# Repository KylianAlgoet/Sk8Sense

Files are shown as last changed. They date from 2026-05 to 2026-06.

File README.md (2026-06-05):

# SK8Sense

Movement Intelligence System voor skateboard coaching.

SK8Sense is een werkend prototype van een slimme skateboardcoach. Het systeem bestaat uit een sensormodule onder het skateboard en een mobiele app die live beweging, druk, impact en trickpogingen zichtbaar maakt. Het board meet wat een skater zelf niet kan zien: pop, airtime, rotatie, landing en drukverdeling.

Het project werd gemaakt door Kylian Algoet als Final Work voor Multimedia & Creative Technology, academiejaar 2025-2026.

## Status

Dit is geen los idee en geen enkel schermconcept. SK8Sense is een werkend hardware- en softwareprototype:

- de ESP32 leest een MPU6050 en vier FSR-druksensoren uit;
- de sensordata wordt via Bluetooth Low Energy naar de app gestuurd;
- de app toont live pitch, roll, impact, FSR-druk en trickstatus;
- sessies kunnen gestart, gevolgd, gestopt en opgeslagen worden;
- trick-detectie gebeurt regelgebaseerd op de firmware;
- AI-coaching geeft korte feedback op basis van sessie- en trickdata;
- de sensormodule zit in een fysieke 3D-geprinte behuizing voor montage onder het deck.

Terminologie: de eerste breadboardfase was een technische haalbaarheidstest. Het eindresultaat van dit project is een werkend prototype.

## Onderzoeksvraag

Hoe kan technologie het leren van skateboardtricks toegankelijker, meetbaar en motiverender maken zonder dat er constant een fysieke coach nodig is?

SK8Sense beantwoordt die vraag door een bestaand skateboard te veranderen in een meetinstrument. Het prototype registreert elke poging, vertaalt ruwe sensordata naar begrijpelijke feedback en helpt de skater gerichter oefenen.

## Het Probleem

Skateboardtricks leren gebeurt vaak op gevoel. Beginners leren via trial-and-error, YouTube, TikTok of videoanalyse achteraf. Dat helpt, maar het blijft moeilijk om te begrijpen wat er precies fout liep tijdens een poging.

Een ollie of kickflip duurt maar een fractie van een seconde. De belangrijkste techniek zit in ongeveer 200 ms: pop, voetdruk, airtime, rotatie, catch en landing. Een coach kan niet elke microbeweging zien. Een skater die zichzelf filmt ziet vaak wel dat het fout ging, maar niet waarom.

SK8Sense lost dat op door het board zelf te laten meten.

## De Oplossing

SK8Sense bestaat uit twee grote delen:

1. Een sensormodule onder het skateboard.
2. Een mobiele app voor live feedback, sessies, learning en coaching.

De sensormodule meet 100 keer per seconde hoe het board beweegt. De app maakt die data bruikbaar: live dashboard, trickfeed, session summary, learning tab en AI-coaching.

Belangrijk: de trick-detectie is bewust niet als black-box AI gebouwd. De ESP32 herkent tricks met transparante, regelgebaseerde logica op basis van fysica. De AI zit in de coachinglaag, niet in de detectielaag.

## Kernzin

Een coach kijkt naar een leerling. Een sensor kijkt naar elke poging.

## Wat Werkt Er Al?

### Hardware

- ESP32-S WROOM leest alle sensoren uit.
- MPU6050 meet versnelling en rotatie.
- Vier FSR 402 druksensoren meten voetdrukzones.
- BLE-advertising en datastream werken.
- Batterijvoeding werkt stabiel met TP4056 en MT3608 boost converter.
- De module zit in een finale PETG-behuizing met aparte deksel.
- Montage onder het deck is uitgewerkt via centrale positie tussen de trucks.

### Firmware

- 100 Hz sensor sampling.
- JSON-payload via BLE Notify.
- Regelgebaseerde trick-detectie.
- Airtime-detectie via acceleratie.
- Flip- en shove-it-detectie via gyroscooppieken.
- FSR-data wordt meegestuurd naar de app.
- I2C-stabiliteit verbeterd met 100 kHz bus clock.

### App

- Login en registratie via Firebase.
- Onboarding flow.
- BLE scan en connect flow.
- Live dashboard met pitch, roll, impact en FSR-bars.
- Live board visualisatie.
- Start/stop live session.
- Trick detection feed.
- Session summary.
- Trick breakdown.
- Session log via Firestore.
- Learning tab voor ollie, kickflip en pop shove-it.
- Trick intro met stappen.
- Practice mode met pogingfeedback.
- Profile en history flow.
- AI Coach feedback via Claude Haiku.

## Product Flow

De app is opgebouwd rond de echte flow van een skater:

1. Open de app.
2. Log in of registreer.
3. Zet het board aan.
4. Scan naar `SK8Sense`.
5. Verbind via BLE.
6. Kalibreer het board plat.
7. Start een live session.
8. Skate en laat het board data meten.
9. Bekijk live feedback en trick-detecties.
10. Stop de sessie.
11. Bekijk summary, trick breakdown en AI-analyse.
12. Oefen verder via de learning tab.

## Live Session

De live session is het hart van SK8Sense.

Tijdens een live session toont de app:

- sessietimer;
- aantal detecties;
- status van de sensorconnectie;
- pitch;
- roll;
- impact;
- tail pressure;
- FSR-druk voor nose, heel, toe en tail;
- live board visualisatie;
- detection banner bij trickherkenning;
- recente trickfeed;
- AI-tip of coachingtip.

De app gebruikt de firmware-output als primaire detectiebron. Wanneer de ESP32 een trick classificeert, logt de app die poging in de actieve sessie.

## Session Summary

Na `END SESSION` toont de app een summary:

- totale duur;
- aantal tricks;
- tricks per minuut;
- max impact;
- trick breakdown per tricktype;
- volledige trick log met timestamps;
- AI Coach analyse van de sessie.

Wanneer een gebruiker ingelogd is, wordt de sessie opgeslagen in Firestore. Daardoor kan de app sessiegeschiedenis en progressie tonen.

## Learning Tab

De learning tab helpt skaters om de MVP-tricks stap voor stap te begrijpen.

| Trick | Doel |
| --- | --- |
| Ollie | De basis: pop, slide, board levelen en landen |
| Kickflip | Flick, fliprotatie, catch en landing |
| Pop shove-it | Tail scoop en horizontale boardrotatie |

Elke trick heeft:

- eigen trick card;
- moeilijkheid;
- categorie;
- korte beschrijving;
- movement breakdown;
- stappen met tips;
- start practice knop.

## Practice Mode

Practice mode is de oefenflow van de app. De skater werkt eerst door losse stappen en daarna door volledige pogingen.

Practice mode bevat:

- timer;
- huidige trick;
- stapvoortgang;
- boardvisualisatie;
- pogingresultaat;
- korte coachingtip;
- rounds van vijf pogingen;
- success rate per round;
- practice summary.

Als een board verbonden is, toont de app dat er live sensorcontext aanwezig is. Zonder board kan practice mode in simulatiemodus gebruikt worden om de learning flow te testen.

## Detectie: Geen Black Box

SK8Sense gebruikt geen AI om de trick zelf te raden. De detectie is regelgebaseerd en draait op de ESP32. Dat maakt de werking uitlegbaar en snel.

De firmware kijkt naar:

- totale acceleratiemagnitude;
- airtime;
- landing impact;
- piekrotatie rond X-as;
- piekrotatie rond Y-as;
- FSR-drukwaarden als extra context.

State machine:

```text
IDLE -> AIRTIME -> LANDING -> IDLE
```

Belangrijkste drempels:

```cpp
AIRTIME_MAG_MAX = 6.5f
LAND_MAG_MIN    = 15.0f
AIRTIME_MIN_MS  = 80
KICK_THRESHOLD  = 180.0f
HEEL_THRESHOLD  = 180.0f
SHUV_THRESHOLD  = 160.0f
```

Ondersteunde detecties:

| Trick | Detectielogica |
| --- | --- |
| Ollie | Airtime zonder dominante flip- of shuv-rotatie |
| Kickflip | Sterke positieve X-rotatie tijdens airtime |
| Heelflip | Sterke negatieve X-rotatie tijdens airtime |
| Backside shuv  | Sterke Y-rotatie in backside richting |
| Frontside shuv | Sterke Y-rotatie in frontside richting |

## AI Coaching

De AI-laag wordt pas gebruikt nadat een trick of sessie al gemeten is. Claude Haiku vertaalt de data naar korte, bruikbare coachingtaal.

De feedbackregels:

- maximaal kort;
- geen lange uitleg;
- skate-taal;
- externe focus;
- gericht op de volgende poging;
- niet "buig je knieen", maar "stay over the bolts".

Voorbeelden van de gewenste toon:

```text
Stay over the bolts.
Pop through the tail.
Catch it closer to the board.
Keep the board under you.
```

## Hardware Architectuur

```text
Skateboard
  ESP32-S WROOM
    MPU6050 via I2C
    FSR nose via ADC
    FSR heel via ADC
    FSR toe via ADC
    FSR tail via ADC
    BLE Notify
      -> React Native app
           live dashboard
           session store
           AI coaching
           Firebase
```

## Hardware Componenten

| Component | Functie | Status |
| --- | --- | --- |
| ESP32-S WROOM 38-pin | Microcontroller + BLE | Werkend |
| MPU6050 | Accelerometer + gyroscoop | Werkend op 100 Hz |
| 4x FSR 402 | Drukzones onder griptape  | Alle 4 geisoleerd werkend |
| LiPo 3.7V 2000 mAh | Batterij | Werkend |
| TP4056 | LiPo laadmodule | Werkend |
| MT3608 | Boost van 3.7V naar 5V | Noodzakelijk en werkend |
| Schuifschakelaar | Aan/uit | Werkend |
| Perfboard | Permanente montage | Gesoldeerd |
| PETG-behuizing | Bescherming onder deck | Finale versie |

## Pinout

| Onderdeel | ESP32 pin | Functie |
| --- | --- | --- |
| MPU6050 SDA | GPIO21 | I2C data |
| MPU6050 SCL | GPIO22 | I2C clock |
| FSR nose pocket | GPIO34 | ADC |
| FSR heel side | GPIO35 | ADC |
| FSR toe side | GPIO32 | ADC |
| FSR tail pocket | GPIO33 | ADC |
| Voeding | VIN/5V | Via MT3608 boost |
| GND | GND | Gemeenschappelijke massa |

FSR voltage divider:

```text
3.3V -> FSR -> ADC pin -> 10k ohm -> GND
```

Belangrijk leerpunt: de 10k pull-down weerstanden moeten naar GND, niet naar SVP/GPIO36.

## Sensorplaatsing

De sensormodule zit centraal onder het deck, tussen de trucks.

Waarom daar:

- de trucks beschermen de module beter tegen directe impact;
- het middelpunt geeft representatieve boardbeweging;
- de module zit niet onder de voeten;
- de montage kan logisch via skateboard bolts en truckposities;
- de sensor verandert het skategevoel niet.

De FSR-sensoren zitten onder het griptape op vier drukzones:

| FSR | Positie | Wat het meet |
| --- | --- | --- |
| Nose pocket | Voorste voet vooraan | Nose press, manual, catch-context |
| Heel side | Hielzijde | Kickflip/flick-context |
| Toe side | Teenzijde | Heelflip/flick-context |
| Tail pocket | Achterste voet | Pop-kracht |

## Behuizing

De behuizing werd iteratief ontwikkeld:

1. Eerste rode PLA-print om maatvoering en indeling te testen.
2. Grotere finale PETG-versie voor de echte integratie.
3. Aparte zwarte deksel.
4. Openingen voor laadpoort, schakelaar en kabeldoorvoer.
5. Montage met skateboard bolts en moeren via de truck-bolt-posities.

PETG is gekozen voor de finale versie omdat het taaier is dan PLA, beter tegen warmte kan en geschikter is voor trillingen onder een skateboard.

## Voeding

De originele aanname was dat een LiPo direct genoeg zou zijn voor de ESP32 NodeMCU. Dat bleek fout.

Probleem:

- LiPo levert 3.7V nominaal en 4.2V volledig geladen.
- De AMS1117-regulator op de ESP32 NodeMCU vraagt ongeveer 4.5V of meer op VIN.
- BLE-pieken deden de spanning zakken.
- Resultaat: BLE advertising werkte niet betrouwbaar op batterij.

Fix:

```text
LiPo -> TP4056 -> MT3608 boost naar 5V -> schakelaar -> ESP32 VIN
```

Na de MT3608 werkte BLE op batterij stabiel.

## BLE Protocol

Device name:

```text
SK8Sense
```

Service UUID:

```text
4fafc201-1fb5-459e-8fcc-c5c9c331914b
```

Characteristic UUID:

```text
beb5483e-36e1-4688-b7f5-ea07361b26a8
```

Voorbeeldpayload:

```json
{
	"ax": -4.3,
	"ay": 0.4,
	"az": 8.0,
	"gx": -5.8,
	"gy": 1.3,
	"gz": 0.6,
	"trick": "none",
	"f1": 0,
	"f2": 0,
	"f3": 0,
	"f4": 0
}
```

Velden:

| Veld | Betekenis |
| --- | --- |
| `ax`, `ay`, `az` | Acceleratie in m/s^2 |
| `gx`, `gy`, `gz` | Gyroscooprotatie in deg/s |
| `trick` | Herkende trick of `none`  |
| `f1` | FSR nose, 0-1023 |
| `f2` | FSR heel, 0-1023 |
| `f3` | FSR toe, 0-1023 |
| `f4` | FSR tail, 0-1023 |

## Testresultaten

Het prototype werd getest via PlatformIO Serial Monitor, Expo dev client en field tests.

### Bench Tests

| Test | Resultaat |
| --- | --- |
| Boot test | Status actief binnen 3 seconden |
| BLE bereik | Stabiel tot ongeveer 8 meter in open ruimte |
| Sample rate | 100 Hz gedurende 60 seconden |
| Packet loss | Minder dan 2 procent |
| Batterijstream | 6+ uur bevestigd met 2000 mAh LiPo |
| FSR isolatie | Alle 4 sensoren onafhankelijk werkend |
| Pitch/roll | Live zichtbaar in app |

### Gemeten waarden

| Situatie | Waarde |
| --- | --- |
| Rust plat | AX ongeveer -4.38, AY ongeveer 0.40, AZ ongeveer 7.96 m/s^2 |
| Gyro drift stil | Minder dan 0.5 deg/s |
| FSR ruis los | Ongeveer 300 ADC, weggefilterd met threshold |
| Live kanteling  | Pitch -21.4 graden, roll 26.7 graden correct zichtbaar |

### Field Test

Het prototype werd niet alleen op tafel getest. Er is ook getest in een echte skatecontext met board, spot en live dashboard. De field test bevestigde dat hardware, app-interface en gebruikssituatie samen logisch voelen.

Getest:

- board statisch bewegen;
- pitch en roll kantelen;
- FSR-drukzones activeren;
- volledige sessieflow;
- kickflip/ollie/shuv detectie via gyro en airtime;
- appfeedback tijdens live sessie.

## Wat Misging En Hoe Het Gefixt Is

De fouten zijn belangrijk omdat ze bewijzen dat het prototype echt gebouwd, getest en verbeterd werd.

| Fail | Oorzaak | Fix |
| --- | --- | --- |
| BLE werkte niet op batterij | AMS1117 kreeg te weinig VIN uit LiPo | MT3608 boost converter toegevoegd |
| FSR cross-talk | Pull-downs naar SVP/GPIO36 in plaats van GND | Alle weerstanden naar GND verplaatst |
| Alle FSR's lazen 0 | Losse 3.3V en koude lassen | Verbindingen opnieuw gesoldeerd |
| MPU6050 viel weg bij trilling | I2C op 400 kHz te gevoelig op perfboard | `Wire.setClock(100000)` |
| Boardnaam niet zichtbaar in BLE scan | Naam zat in scan response | Service UUID expliciet geadverteerd |
| 3D viewer instabiel | expo-gl incompatibel met RN 0.81.5 | Stabiele Animated fallback |
| Pitch/roll bleef 0.0 graden | Stale closure in BLE callback | Waarden direct uit sensorData berekend |

## Markt En Doelgroep

SK8Sense richt zich op een duidelijke marktgap: veel skaters leren zelfstandig, maar er bestaat weinig toegankelijke sport-tech die specifiek skateboardtricks meet en coacht.

Doelgroep:

- leeftijd 14-25;
- beginner tot intermediate;
- skaters die tricks willen leren zonder dure lessen;
- skaters die zichzelf al filmen maar niet weten waarom een poging misgaat;
- coaches die objectieve data per leerling willen.

Personas uit het magazine:

| Persona | Profiel | Waarom SK8Sense helpt |
| --- | --- | --- |
| Kobe, 16  | Beginner, skatet 6 maanden  | Wil weten wat fout gaat bij tricks |
| Lars, 22  | Intermediate, data-gedreven | Wil consistentie meten |
| Elien, 28 | Skatecoach | Wil data over elke poging van leerlingen |

## Scope

### Must Have

- BLE-verbinding ESP32 naar app.
- Realtime IMU-streaming op 100 Hz.
- Trick-detectie voor ollie, kickflip en shove-it logica.
- Sessies opnemen en bewaren.
- Firebase gebruikersauthenticatie.
- Live board visualisatie met pitch en roll.

### Should Have

- Vier FSR-druksensoren.
- AI-coaching via Claude Haiku.
- Profiel met statistieken.
- Sessie-samenvatting.
- Kalibratie van sensoren.

### Could Have

- 3D skateboardvisualisatie.
- Leermodule met stap-voor-stap tricks.
- Video-synchronisatie.
- Multiplayer of vrienden vergelijken.

### Bewust Niet In MVP

- TensorFlow Lite on-device ML.
- Volledig FSR-gebaseerde trick-detectie.
- iOS-build.
- Betaalsysteem.

## Design

Het design-systeem heet MIS v3: Movement Intelligence System.

De app moest niet voelen als een bankapp of generieke fitnessapp. De visuele richting is een neo-brutalist performance OS: donker, hoekig, data-gedreven en geloofwaardig binnen skatecultuur.

Designprincipes:

- data moet snel scanbaar zijn tussen pogingen;
- elke screen heeft een duidelijke taak;
- feedback moet bruikbaar zijn, geen decoratie;
- skatecultuur en technische precisie moeten samenkomen;
- statuskleuren worden functioneel gebruikt;
- oranje accentkleur markeert actie, detectie en feedback.

Belangrijke stijlkeuzes:

| Element | Keuze |
| --- | --- |
| Achtergrond  | Void black |
| Accent | Signal orange |
| Display font | Archivo |
| Data labels  | IBM Plex Mono |
| Body text | Space Grotesk |
| Componenten  | Ticked panels, RegStrip, MotionAI, chips, stat grids |

Design tokens:

```text
app/design-tokens.js
docs/design/design-tokens-reference.js
```

## Tech Stack

### App

| Onderdeel | Technologie |
| --- | --- |
| Framework | React Native |
| Runtime | Expo SDK 54 |
| Navigatie | React Navigation |
| State | Zustand |
| BLE | react-native-ble-plx |
| Auth | Firebase Auth |
| Database  | Firestore |
| AI | Anthropic Claude API |
| Fonts | Archivo, IBM Plex Mono, Space Grotesk |

### Firmware

| Onderdeel | Technologie |
| --- | --- |
| Platform | ESP32 Arduino  |
| Build tool  | PlatformIO |
| BLE stack | NimBLE-Arduino |
| JSON | ArduinoJson |
| IMU library | MPU6050 |
| Sensor bus  | I2C op 100 kHz |

## Projectstructuur

```text
SK8Sense/
  app/
    App.js
    app.json
    package.json
    screens/
      HomeScreen.js
      ConnectScreen.js
      DashboardScreen.js
      SessionSummaryScreen.js
      LearningScreen.js
      TrickIntroScreen.js
      PracticeScreen.js
      ProfileScreen.js
      HistoryScreen.js
    components/
      LiveBoardViewer.js
      SkateboardGL.js
      V3Shared.js
    store/
      bleStore.js
      sessionStore.js
      trickStore.js
      authStore.js
      mockBle.js
    services/
      aiCoach.js
    config/
      firebase.js
  firmware/
    platformio.ini
    src/
      main.cpp
  docs/
    magazine-process.md
    hardware-research-final.md
    sensor-mounting-final.md
    sprint-planning.md
    design/
      design-tokens-reference.js
    test-logs/
      logs.txt
    magazine/
  hardware/
    enclosure/
      skatesense_base.stl
      skatesense_lid.stl
      electronics_base.stl
      electronics_lid.stl
      UM2C_electronics_enclosure.ufp
  models/
  archive/
    legacy-nested-repo/       oude kopie, niet actief
```

Gebruik voor ontwikkeling de top-level `app/` map. De oude geneste kopie is bewaard in `archive/legacy-nested-repo/`, maar is geen actief startpunt.

## App Installeren En Draaien

Vereisten:

- Node.js 20.19.4 of nieuwer;
- npm;
- Expo tooling via `npx expo`;
- Android toestel voor echte BLE;
- Expo development build/dev client voor native BLE.

Installatie:

```powershell
cd C:\Users\kylia\Sk8Sense\app
npm install
npx expo start
```

Scripts:

```powershell
npm run android
npm run ios
npm run web
```

BLE werkt niet in Expo Go. Gebruik een development build/dev client voor echte Bluetooth-functionaliteit. Op web kan het dashboard met mock sensordata draaien.

## Firebase Config

Firebase wordt gebruikt voor:

- login;
- registratie;
- sessies opslaan;
- sessiegeschiedenis laden.

Configbestand:

```text
app/config/firebase.js
```

## AI Coach Config

Maak lokaal dit bestand aan:

```text
app/config/ai.js
```

Voorbeeld:

Zet voor echte AI-feedback een lokale environment variable:

```powershell
$env:EXPO_PUBLIC_ANTHROPIC_API_KEY='your-api-key'
```

Zonder key blijft de app werken, maar de AI Coach geeft dan geen gegenereerde tekst terug.

## Firmware Builden En Uploaden

Vereisten:

- PlatformIO;
- ESP32 via USB;
- juiste COM-poort.

Commando's:

```powershell
cd C:\Users\kylia\Sk8Sense\firmware
pio run
pio run --target upload
pio device monitor
```

De huidige configuratie gebruikt `COM3`. Pas dit aan in:

```text
firmware/platformio.ini
```

## Hardware Bouwen

Benodigdheden:

- ESP32-S WROOM 38-pin;
- MPU6050 GY-521;
- 4x FSR 402;
- 4x 10k ohm weerstand;
- LiPo 3.7V 2000 mAh;
- TP4056 laadmodule;
- MT3608 boost converter;
- schuifschakelaar;
- perfboard;
- soepele draad;
- krimpkous;
- soldeerbout;
- 3D-geprinte behuizing.

Bekabeling:

```text
MPU6050
3V3  -> VCC
GND  -> GND
GPIO21 -> SDA
GPIO22 -> SCL

FSR per sensor
3V3 -> FSR -> ADC pin -> 10k ohm -> GND

Voeding
LiPo -> TP4056 -> MT3608 -> schakelaar -> ESP32 VIN/5V
```

## Bekende Beperkingen

SK8Sense is een werkend prototype, geen consumentenproduct.

Bekende beperkingen:

- iOS-build is buiten scope gebleven door Apple Developer-kost.
- Volledige drop-test op 80 cm en land-simulatie zijn gepland voor v2.
- AI-coaching hangt af van correcte detectie en goede sensorcontext.
- FSR's worden nu vooral gebruikt voor drukvisualisatie en context, niet als primaire trickclassifier.
- TensorFlow Lite modellen zijn nog niet toegevoegd.
- Een productieversie vraagt een compactere PCB, betere waterbescherming en langere duurtests.

## Roadmap

- Tappable trick detail na sessie.
- Clean score per poging.
- Diepere analyse per trick: pop timing, airtime, catch en landing.
- Meer sensor-gedreven feedback in practice mode.
- Video synchroniseren met sensor-events.
- Meer tricks toevoegen.
- TFLite model trainen op echte skate-data.
- PCB ontwerpen in plaats van perfboard.
- Waterbestendigere behuizing.
- Productievere montage en kabelgeleiding.

## Documentatie In Deze Repo

- `docs/magazine-process.md` - volledige procesdocumentatie.
- `docs/hardware-research-final.md` - hardware research.
- `docs/sensor-mounting-final.md` - sensorplaatsing en bescherming.
- `docs/sprint-planning.md` - planning en proces.
- `docs/magazine/` - magazinecontent en screenshots.

## Bronnenbasis

De keuzes in SK8Sense zijn onderbouwd met onderzoek naar:

- motorisch leren en feedback;
- externe-focus instructies;
- IMU-gebaseerde trickherkenning;
- BLE voor kleine realtime sensordatapakketten;
- ESP32 datasheets;
- MPU6050 datasheets;
- FSR datasheets;
- Expo, React Native, Firebase en BLE-documentatie.

Belangrijkste inhoudelijke lijn:

- Schmidt & Lee: motorisch leren en feedback.
- Wulf, Shea & Lewthwaite: externe focus werkt beter dan interne focus.
- Tang et al.: IMU-data kan gebruikt worden voor skateboard trick recognition.
- Bluetooth SIG: BLE is geschikt voor kleine low-power datastreams.
- Espressif, InvenSense en Interlink: hardwarekeuzes en sensorwerking.

## Conclusie

SK8Sense toont dat technologie skateboardtricks toegankelijker, meetbaar en motiverender kan maken zonder dat er constant een fysieke coach naast de skater staat.

Het prototype doet dat door een bestaand skateboard uit te breiden met sensoren, de data live naar een mobiele app te sturen, tricks regelgebaseerd te herkennen en de skater feedback te geven die direct bruikbaar is voor de volgende poging.

De belangrijkste nuance blijft: de intelligentie zit niet in magische detectie, maar in een eerlijke combinatie van fysica, sensordata, transparante logica en korte coaching.

## Auteur

Kylian Algoet  
Multimedia & Creative Technology  
Final Work 2025-2026  
SK8Sense - Movement Intelligence System v0.9

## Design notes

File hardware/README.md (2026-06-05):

# Hardware

This folder contains physical build files for the SK8Sense sensor module.

```text
enclosure/    STL and Ultimaker project files for the electronics enclosure
```

The active firmware is not stored here. Use `../firmware/` for ESP32 code.

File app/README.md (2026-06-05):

# SK8Sense App

This is the active mobile app for SK8Sense.

Use this folder as the only app entry point. The app receives BLE data from the ESP32 sensor module, shows live telemetry, logs sessions, exposes the learning flow and calls the AI coach.

## Run

```powershell
npm install
npx expo start
```

BLE does not work in Expo Go. Use an Expo development build/dev client on a real Android device for Bluetooth testing.

Use Node.js 20.19.4 or newer for React Native 0.81.5.

## Important folders

```text
screens/      App screens and user flows
components/   Shared UI and board visualisation
store/        Zustand stores for BLE, auth, sessions and tricks
services/     AI coach integration
config/       Firebase config and local AI config
assets/       Icons, splash and skateboard models
```

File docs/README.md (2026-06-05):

# Documentation

Project documentation for SK8Sense.

```text
magazine-process.md          Full process report
hardware-research-final.md   Hardware choices and prototype evaluation
sensor-mounting-final.md     Sensor placement, protection and test method
sprint-planning.md           Planning and weekly process
design/                      Design references
test-logs/                   Raw or exported test logs
magazine/                    Magazine content and screenshots
```

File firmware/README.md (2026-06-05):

# SK8Sense Firmware

This is the active ESP32 firmware for SK8Sense.

The firmware reads the MPU6050 and four FSR sensors, classifies tricks with rule-based logic and streams compact JSON packets over Bluetooth Low Energy.

## Build and upload

```powershell
pio run
pio run --target upload
pio device monitor
```

The current `platformio.ini` uses `COM3`. Change `upload_port` and `monitor_port` if the ESP32 appears on another port.

## Hardware pins

```text
GPIO21  MPU6050 SDA
GPIO22  MPU6050 SCL
GPIO34  FSR nose
GPIO35  FSR heel
GPIO32  FSR toe
GPIO33  FSR tail
```

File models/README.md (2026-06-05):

# Models

Reserved for future machine-learning models.

The current SK8Sense prototype uses rule-based trick detection on the ESP32 firmware. TensorFlow Lite or other trained models can be added here in a later version.

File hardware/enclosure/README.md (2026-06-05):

# Enclosure Files

3D-print and slicer files for the SK8Sense electronics enclosure.

```text
skatesense_base.stl
skatesense_lid.stl
electronics_base.stl
electronics_lid.stl
UM2C_electronics_enclosure.ufp
```

These files are build artifacts for the physical prototype. They are separate from the mobile app and firmware code.

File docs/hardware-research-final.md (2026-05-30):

# SK8SENSE
## Hardware Research Document — FINALE VERSIE
### Onderbouwing van technologische keuzes + Evaluatie na prototype
**Kylian Algoet**
**Multimedia & Creatieve Technologie**
**Final Work — Academiejaar 2025–2026**

---

## 1. Inleiding

Dit document beschrijft het onderzoek naar de hardware componenten die geselecteerd zijn voor de ontwikkeling van het SK8Sense prototype, aangevuld met de definitieve evaluatie na afronding van de bouw. Naast de oorspronkelijke onderbouwing van elke keuze bevat dit document ook de bevindingen uit de praktijk: problemen die optraden, aanpassingen die nodig waren, en componenten die aan het originele plan werden toegevoegd.

Het project SK8Sense vereist een sensormodule die onder een skateboard bevestigd kan worden, beweging en druk meet, en deze data draadloos naar een mobiele applicatie stuurt. Dit document bespreekt elk component dat hiervoor gebruikt werd.

---

## 2. Onderzoeksmethode

Voor het selecteren van de juiste componenten werden de volgende criteria gehanteerd:

- Technische geschiktheid voor het meten van skateboard beweging en druk
- Kostprijs binnen het budget van een studentenproject
- Levertijd compatibel met de projectplanning van 5 weken
- Beschikbaarheid van documentatie en community support
- Compatibiliteit met de gekozen software stack (React Native, Arduino IDE)
- Energieverbruik passend bij draagbaar gebruik op batterij
- Robuustheid voor outdoor gebruik en mechanische schokken

Voor elke componentcategorie werden minimaal twee alternatieven onderzocht en vergeleken aan de hand van bovenstaande criteria.

---

## 3. Microcontroller — ESP32

### 3.1 Gekozen oplossing
**NodeMCU ESP32-S WROOM 38-pin**

De ESP32-S is een dual-core 240MHz microcontroller met geïntegreerde Wi-Fi en Bluetooth Low Energy (BLE). Voor SK8Sense is BLE de cruciale feature, aangezien de sensor draadloos data naar de mobiele app moet sturen.

### 3.2 Onderzochte alternatieven

| Optie | Voordelen | Nadelen | Verdict |
|---|---|---|---|
| ESP32-S (gekozen) | BLE ingebouwd, 18 ADC pinnen, goedkoop, Arduino IDE compatible | Iets hoger verbruik dan nRF52 | **GEKOZEN** |
| Arduino Nano 33 BLE | Goede BLE, ingebouwde IMU | Duurder (€25), minder ADC pinnen | Te duur |
| Raspberry Pi Pico W | Krachtig, Wi-Fi | Geen BLE op alle modellen, complexer | BLE inconsistent |
| Arduino Uno + HC-05 module | Bekend, simpel | Klassieke Bluetooth (geen BLE), groot | Verouderde Bluetooth |

### 3.3 Onderbouwing keuze

De ESP32-S werd gekozen om de volgende redenen:
- Bluetooth Low Energy is essentieel voor draadloze communicatie met minimaal energieverbruik
- Ingebouwde dual-core processor laat toe om sensor sampling en BLE communicatie parallel uit te voeren
- 18 analoge inputs zijn voldoende voor de IMU (I2C) en de 4 FSR druksensoren (analoog)
- Programmeerbaar via Arduino IDE (via PlatformIO), wat de leercurve verlaagt
- Prijs van circa €10 maakt het mogelijk om een backup module te bestellen
- Uitgebreide community en documentatie versnellen het ontwikkelproces

### 3.4 Aankoop
Twee stuks besteld bij Otronic.nl (NL), levertijd 1 tot 3 werkdagen naar België.

### 3.5 ⚠️ Bevinding na prototype — Kritiek voltageprobleem

**Probleem ontdekt tijdens testen:**
De ESP32 NodeMCU bevat een AMS1117-3.3 LDO-spanningsregelaar die minimaal **4.5–4.8V** nodig heeft op de VIN-pin om stabiel 3.3V te leveren aan de microcontroller. Een LiPo-batterij levert slechts 3.7V (nominaal) tot 4.2V (volledig geladen).

**Gevolg:** Wanneer de ESP32 op batterij werd aangesloten, functioneerde de chip op het randje. Bij het opstarten van de BLE-radio — die korte vermogenspieken van 200–250mA veroorzaakt — zakte de spanning onder de drempelwaarde van de LDO, waardoor de chip resettte of BLE niet startte.

**Symptomen:**
- LED brandde zwakker op batterij dan op USB
- BLE advertisement was niet detecteerbaar via de telefoon
- ESP32 startte op maar de BLE scanning in de app vond het apparaat niet

**Oplossing — MT3608 Boost Converter:**
Een MT3608 DC-DC step-up converter werd toegevoegd aan het circuit. Deze verhoogt de 3.7–4.2V van de LiPo naar een stabiele 5V, ingesteld via een trimmer weerstand. Deze 5V gaat naar de VIN-pin van de ESP32, waarna de interne AMS1117 regelaar correct 3.3V levert aan alle componenten.

**Circuit na aanpassing:**
```
Batterij+ → TP4056 B+ → TP4056 OUT+ → MT3608 IN+ → MT3608 OUT+(5V) → Schakelaar → ESP32 VIN
Batterij- → TP4056 B- → TP4056 OUT- → MT3608 IN- → ESP32 GND
```

**Leerpunt:** Bij het selecteren van een microcontroller voor batterijgevoed gebruik is de minimum input voltage van de interne spanningsregelaar een kritieke parameter die vooraf gecontroleerd moet worden.

---

## 4. IMU Bewegingssensor — MPU6050

### 4.1 Gekozen oplossing
**MPU6050 GY-521 module**

De MPU6050 is een 6-axis Inertial Measurement Unit met een 3-axis accelerometer en 3-axis gyroscoop. De sensor communiceert via I2C met de ESP32 en kan tot 1000 samples per seconde leveren, wat ruim voldoende is voor de gewenste 100Hz sampling rate.

### 4.2 Onderzochte alternatieven

| Optie | Specificaties | Prijs | Verdict |
|---|---|---|---|
| MPU6050 (gekozen) | 6-axis, I2C, ±16g, ±2000°/s | €4–5 | **GEKOZEN** |
| MPU9250 / MPU9265 | 9-axis (incl. magnetometer) | €10–15 | Magnetometer niet nodig |
| BNO055 | 9-axis met sensor fusion | €25–30 | Te duur |
| ADXL345 (alleen accel) | 3-axis accelerometer | €3 | Geen gyroscoop |

### 4.3 Onderbouwing keuze

De MPU6050 is voor SK8Sense ideaal omdat:
- De 6-axis configuratie laat toe om zowel translatie (acceleratie) als rotatie (gyroscoop) te meten — beide cruciaal voor trick detectie
- Een magnetometer (zoals in de MPU9250) is niet nodig voor skate tricks, en zou interferentie veroorzaken bij metalen onderdelen in skateparken
- Het bereik van ±8g op de accelerometer (geconfigureerd in firmware) is voldoende voor de pop kracht van een ollie
- De sensor wordt al jaren gebruikt in onderzoek en hobbyprojecten, met betrouwbare libraries voor Arduino
- De prijs is laag genoeg om een backup te kopen

### 4.4 Bevindingen na prototype

**I2C betrouwbaarheid op perfboard:**
Bij de overgang van breadboard naar gesoldeerd perfboard traden intermitterende I2C-verbindingsproblemen op (`Wire.cpp: requestFrom(): i2cWriteReadNonStop returned Error 263`). Dit bleek te wijten aan twee oorzaken:

1. **Koude lassen** op de VCC en GND verbindingen van de MPU6050 zorgden voor wisselend contact bij beweging. Opgelost door alle verbindingen te hersolleren tot glanzende verbindingen.
2. **Snelheid van de I2C bus**: de standaard kloksnelheid van 400kHz bleek gevoeliger voor ruis op een perfboard. Door `Wire.setClock(100000)` toe te voegen (100kHz), werden alle I2C-fouten geëlimineerd ten koste van een minimaal hogere latency — volledig acceptabel voor 100Hz sampling.

**Trick detectie met gyroscoop:**
De gyroscoop bleek betrouwbaar genoeg voor de detectie van kickflips (rotatie rond de lengterichting, GX-as) en shove-its (rotatie rond de verticale as, GY-as) op basis van piekwaarden tijdens de luchttijd. Drempelwaarden werden empirisch vastgesteld:
- Kickflip: GX piek > 180°/s
- Heelflip: GX piek < –180°/s
- BS/FS Shove-it: |GY| piek > 160°/s

---

## 5. Drukmeting — FSR Sensoren

### 5.1 Gekozen oplossing
**4× Adafruit Round Force-Sensitive Resistor (FSR 402, C3063-003, 12mm)**

Force Sensitive Resistors zijn dunne, flexibele drukstrips die hun weerstand aanpassen op basis van toegepaste kracht. Ze zijn ideaal voor het meten van voetdruk op een skateboard omdat ze plat genoeg zijn om onder griptape te plaatsen zonder zichtbaar te zijn.

### 5.2 Onderzochte alternatieven

| Optie | Voordelen | Nadelen | Verdict |
|---|---|---|---|
| FSR 12mm rond (gekozen) | Plat, betaalbaar, snel | Slechts puntmeting, geen zone | **GEKOZEN** |
| Velostat drukmat (DIY) | Volledige drukheatmap | Complex, fragile, veel kabels | Te ambitieus voor 5 weken |
| Load cells | Hoge precisie | Te dik, niet flexibel | Niet geschikt voor onder griptape |
| Capacitieve sensoren | Geen mechanische slijtage | Complex te kalibreren, duur | Buiten budget en tijd |

### 5.3 Onderbouwing keuze

Vier FSR sensoren werden gekozen omdat:
- Vier zones (neus, hiel, teen, staart) leveren genoeg informatie om verschillende tricks te onderscheiden
- De 12mm ronde versie is groot genoeg om voetdruk betrouwbaar te detecteren maar klein genoeg om onder griptape te passen
- FSR sensoren zijn passieve componenten — geen voeding nodig, alleen een voltage divider met een 10kΩ weerstand
- Een vijfde FSR werd besteld als backup

### 5.4 Schakelschema per FSR (voltage divider)
```
ESP32 3.3V ──── FSR poot 1
                FSR poot 2 ──── GPIO pin (ADC)
                                    │
                                  10kΩ
                                    │
                                   GND
```

GPIO toewijzing: Nose → GPIO34, Heel → GPIO35, Toe → GPIO32, Tail → GPIO33

### 5.5 ⚠️ Bevindingen na prototype — Meerdere kritieke fouten

**Fout 1 — Weerstanden naar verkeerde referentie (SVP i.p.v. GND):**
Tijdens de eerste soldeersessie werden alle 10kΩ weerstanden naar de SVP-pin (GPIO36) gesoldeerd i.p.v. naar GND. SVP is een ADC-ingangspin met hoge impedantie, wat betekende dat alle FSR-signaallijnen een gemeenschappelijk referentiepunt deelden. Het gevolg: het indrukken van één sensor activeerde alle sensoren tegelijk.

*Oplossing:* Alle weerstanden opnieuw gesoldeerd naar de GND-pin bovenaan links op de ESP32.

**Fout 2 — Koude lassen na hersolleren:**
Na het verplaatsen van de weerstanden waren enkele verbindingen met koude lassen gesoldeerd, waardoor de 3.3V voeding naar de FSR-sensoren niet doorging en alle sensoren 0 lazen.

*Oplossing:* Elke verbinding controleerd op glanzend uiterlijk, koude lassen opnieuw verhit en aangevuld met soldeertin.

**Fout 3 — GND van MPU6050 via weerstand:**
Bij één soldeersessie werd de GND van de MPU6050 abusievelijk via een weerstand verbonden naar de ESP32 GND, in plaats van direct. Dit veroorzaakte een spanningsval op de GND-lijn, wat leidde tot I2C-fouten.

*Oplossing:* GND altijd direct verbinden, nooit via een weerstand.

**Eindresultaat na alle correcties:**
Alle 4 FSR-sensoren werken volledig geïsoleerd en reageren correct op druk. Testresultaten:
- Nose (GPIO34): ruststatus 0, bij druk ~3900–4095/4095
- Heel (GPIO35): ruststatus 0, bij druk ~3900–4095/4095
- Toe (GPIO32): ruststatus 0, bij druk ~3900–4095/4095
- Tail (GPIO33): ruststatus 0, bij druk ~3900–4095/4095

---

## 6. Voeding — LiPo + TP4056 + MT3608

### 6.1 Gekozen oplossing
**LiPo 3.7V 2000mAh + TP4056 micro-USB oplaadmodule + MT3608 boost converter**

> **Nota:** De originele planning voorzag een 1000mAh batterij zonder boost converter. Na de ontdekking van het voltageprobleem beschreven in sectie 3.5 werden de keuzes bijgesteld.

### 6.2 Definitieve componentkeuze

| Component | Specificatie | Reden voor keuze |
|---|---|---|
| LiPo batterij | 3.7V, 2000mAh, 103450 | Hogere capaciteit dan origineel gepland, voldoende voor meerdere sessies |
| TP4056 lader | Micro-USB, 5V 1A | Laadt batterij veilig, ingebouwde bescherming |
| MT3608 boost | In: 2–24V, Uit: instelbaar tot 28V | Verhoogt 3.7V naar stabiele 5V voor ESP32 |
| SS12D00G2 schakelaar | SPDT, 300mA rated | Aan/uit knop voor volledige stroomonderbreking |

### 6.3 Herziene stroomberekening

| Component | Verbruik |
|---|---|
| ESP32 (BLE actief) | ~150mA gemiddeld |
| MPU6050 | ~4mA |
| 4× FSR voltage dividers | ~1.3mA |
| MT3608 boost converter efficiëntie | ~10% overhead |
| **Totaal geschat** | **~175mA** |

Met een 2000mAh batterij: 2000 / 175 ≈ **~11 uur theoretisch**, in praktijk **6–8 uur** door BLE piekstromen. Ruim voldoende voor meerdere skatesessies.

### 6.4 TP4056 laadstatus
- **Rode LED:** actief laden
- **Blauwe LED:** volledig geladen (4.2V)

---

## 7. Communicatie — NimBLE (BLE stack)

### 7.1 Gekozen oplossing
**NimBLE-Arduino library v1.4.3**

Voor de BLE-implementatie op de ESP32 werd NimBLE-Arduino gebruikt in plaats van de standaard ESP-IDF Bluetooth stack. NimBLE biedt lagere geheugenvoetafdruk en betrouwbaardere advertising.

### 7.2 BLE protocol

Het apparaat adverteert als "SK8Sense" met een vaste service UUID. De karakteristiek verstuurt JSON-data via NOTIFY op 100Hz:

```json
{
  "ax": -4.37, "ay": 0.40, "az": 7.96,
  "gx": -5.83, "gy": 1.34, "gz": 0.56,
  "trick": "none",
  "f1": 0, "f2": 0, "f3": 0, "f4": 0
}
```

### 7.3 ⚠️ Bevindingen — BLE advertising zichtbaarheid

**Probleem:** Op batterij adverteerde het apparaat correct (verificeerbaar via Serial Monitor), maar was het niet zichtbaar in de BLE-scan van de mobiele app.

**Oorzaak:** NimBLE plaatst de apparaatnaam standaard in de scan response, niet in het hoofdadvertisement-pakket. Sommige Android-versies doen geen actieve scan en missen daardoor de scan response.

**Oplossing:** Service UUID expliciet toegevoegd aan het hoofdadvertisement-pakket:
```cpp
pAdvertising->addServiceUUID(SERVICE_UUID);
```

De app filtert op MAC-adres en naam voor betrouwbare identificatie.

---

## 8. Behuizing — 3D Geprinte Behuizing

### 8.1 Gekozen oplossing
**PLA 3D-geprinte behuizing, ontworpen in Fusion 360**

Een custom behuizing werd ontworpen en geprint om alle elektronica te beschermen tijdens het skaten.

### 8.2 Ontwerpcriteria
- Past op het midden van het skateboard deck (niet interfereren met trucks of voetplaatsing)
- Genoeg ruimte voor ESP32, perfboard met FSR-bedrading, batterij en TP4056
- Toegang voor micro-USB oplading zonder demontage
- Schakelaar zichtbaar en bereikbaar aan de zijkant

### 8.3 Bevindingen
De behuizing werd succesvol geprint en gemonteerd. Kabels naar de FSR-sensoren worden via gaten in de onderkant van de behuizing naar de corners van het deck geleid. De behuizing houdt stand bij normaal gebruik, al zal toekomstige iteraties betere kabelgeleiding en schroefdraad voor de deksel bevatten.

---

## 9. Samenvattend overzicht — Definitieve componentenlijst

| Component | Functie | Aantal | Status |
|---|---|---|---|
| ESP32-S NodeMCU 38-pin | Microcontroller + BLE | 2 | ✅ Werkend |
| MPU6050 GY-521 | 6-axis IMU | 2 | ✅ Werkend (100Hz) |
| Adafruit FSR Round 12mm | Drukmeting × 4 zones | 5 (4+backup) | ✅ Alle 4 werkend |
| LiPo 3.7V 2000mAh | Voeding | 2 | ✅ Werkend |
| TP4056 micro-USB lader | Veilig opladen LiPo | 2 | ✅ Werkend |
| **MT3608 boost converter** | **3.7V → 5V (nieuw)** | **2** | **✅ Oplossing voltage issue** |
| SS12D00G2 schakelaar | Aan/uit | 3 | ✅ Werkend |
| Perfboard | Permanente montage | 2 | ✅ Gesoldeerd |
| 10kΩ weerstanden | Voltage divider FSR | 10 | ✅ |
| Soepele draad set | Bedrading | 1 set | ✅ |
| 3D-geprinte behuizing (PLA) | Bescherming elektronica | 1 | ✅ |

### 9.1 Toegevoegde component t.o.v. oorspronkelijk plan

De **MT3608 boost converter** was niet voorzien in de originele component­selectie. Na het ontdekken dat de AMS1117 LDO op de ESP32 NodeMCU minimaal 4.5V nodig heeft terwijl een LiPo-batterij slechts 3.7–4.2V levert, werd deze component toegevoegd als essentiële schakel in het voedingscircuit.

### 9.2 Totale gerealiseerde kost
De totale hardwarekost bedraagt circa **€125–140** (verzending inbegrepen), inclusief de niet-geplande MT3608 boost converters (€4 per stuk). Dit valt binnen het voorziene budget.

---

## 10. Risicoanalyse — Evaluatie na realisatie

| Risico | Mitigatie gepland | Wat effectief gebeurde |
|---|---|---|
| Componentuitval | 2× van elk kritiek component | Geen uitval tijdens prototype |
| Levertijd | Otronic.nl (1–3 dagen) | Levering binnen 2 werkdagen ✅ |
| Breadboard compatibiliteit ESP32 | ESP32-S gekozen | Geen breadboard-problemen ✅ |
| Mechanische schade tijdens skaten | 3D-geprinte behuizing | Behuizing geprint en gemonteerd ✅ |
| **Voltage issue op batterij** | **Niet voorzien** | **MT3608 toegevoegd als oplossing** |
| **FSR cross-talk / kortsluiting** | **Niet voorzien** | **GND-bedrading gecorrigeerd** |

---

## 11. Conclusie

De geselecteerde hardware vormt een werkende, gebalanceerde combinatie van prestaties, kostprijs en haalbaarheid. Het prototype demonstreert succesvol:

- **100Hz IMU-streaming** via BLE naar de mobiele app
- **Realtime trick detectie** (Ollie, Kickflip, Heelflip, BS/FS Shove-it) op basis van gyroscoop piekwaarden
- **4 onafhankelijke FSR-zones** voor voetdrukdetectie op neus, hiel, teen en staart
- **Draadloos gebruik op batterij** dankzij de toegevoegde boost converter

De twee belangrijkste leerpunten zijn:

1. **Altijd de minimum input voltage van LDO-regelaars controleren** bij batterijgevoed gebruik — dit leidde tot de noodzakelijke toevoeging van de MT3608.
2. **GND-verbindingen nooit via weerstanden** leiden — dit veroorzaakte zowel I2C-instabiliteit als FSR-kortsluiting.

Dit research document dient als naslagwerk én als procesverslag van de werkelijk gemaakte keuzes en ontdekte problemen, geschikt als technische onderbouwing voor de eindjury van het Final Work.

---

*SK8Sense · Hardware Research · Kylian Algoet · MCT · 2025–2026*

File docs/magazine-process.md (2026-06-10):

# SK8SENSE — PROCESVERSLAG
## Movement Intelligence System · Final Work Documentation

---

# 1. BRAINSTORM / MINDMAP

## Centrale vraag
*Hoe kan technologie skateboarden leuker en leerrijker maken?*

## Kernideeën (brainstorm)
- Skaters leren tricks zonder coach → AI als vervanger
- Sensoren meten beweging → objectieve data over je techniek
- Feedback moet aanvoelen als een coach, niet als een app
- Gamification: XP, streaks, progressie bijhouden
- Hardware op het board zelf (niet in de schoen)

## Mindmap structuur
```
SK8SENSE
├── HARDWARE
│   ├── ESP32-S WROOM (microcontroller + BLE)
│   ├── MPU6050 (IMU: versnellingsmeter + gyroscoop)
│   ├── FSR 402 sensoren (druksensoren × 4)
│   ├── TP4056 (LiPo oplader)
│   └── LiPo batterij 2000mAh 3.7V
│
├── SOFTWARE / APP
│   ├── React Native + Expo
│   ├── BLE connectie (react-native-ble-plx)
│   ├── Firebase Auth + Firestore
│   ├── Claude AI coaching (claude-haiku)
│   └── Three.js / Animated (3D visualisatie)
│
├── DETECTIE
│   ├── Airtime detectie (acceleratie < 6.5 m/s²)
│   ├── Kickflip (gyro GX > 180°/s)
│   ├── Heelflip (gyro GX < -180°/s)
│   ├── BS Shove-it (gyro GY > 160°/s)
│   └── Pop detectie (FSR tail spike)
│
└── UX / DESIGN
    ├── Neo-brutalist (MIS v3 design system)
    ├── Skate cultuur taal
    ├── Extern gefocuste feedback
    └── Progressie tracking
```

---

# 2. MOODBOARD

## Visuele richting
- **Stijl:** Neo-brutalist / Cyber Performance OS
- **Referenties:** F1 telemetrie dashboards, militaire HUD interfaces, skateboard magazines (Thrasher, Jenkem)
- **Kleurpalet:**
  - Achtergrond: `#0A0A0B` (void black)
  - Accent: `#FF6A3D` (signal orange)
  - Tekst primair: `#ECECE8` (off-white)
  - Grid overlay: `rgba(255,255,255,0.04)`
- **Typografie:**
  - Archivo ExtraBold (display/headings)
  - IBM Plex Mono (labels, technische data)
  - Space Grotesk (body text)
- **Sfeer:** Industrieel, precies, data-gedreven maar met skate energie

## Moodboard elementen
- Motorsport telemetrie schermen
- Thrasher magazine lay-outs
- Neon-verlichte skate spots
- Circuit board patronen
- Bewegingsanalyse software (Kinovea)

---

# 3. LITERATUURSTUDIE

## Bewegingsanalyse in sport
Literatuur toont aan dat real-time feedback bij het aanleren van motorische vaardigheden significant effectiever is dan uitgestelde feedback (Schmidt & Lee, 2011). Skateboard tricks vereisen precisie timing van maximaal 200ms — menselijke coaches missen dit consistentie.

## BLE voor wearables
Bluetooth Low Energy (BLE 5.0) biedt een theoretisch bereik van 40m met een maximale datarate van 2 Mbps. Voor 100Hz IMU streaming is een bandbreedtevereiste van ~15KB/s nodig — ruim binnen BLE-capaciteit.

## IMU-gebaseerde bewegingsdetectie
De MPU6050 integreert een 3-assige accelerometer (±8g range) en gyroscoop (±500°/s range). Onderzoek naar skateboard trick detectie (Tang et al., 2020) toont aan dat airtime detectie via acceleratie het betrouwbaarste startpunt is, gevolgd door rotatieanalyse via gyroscoop.

## FSR sensoren in sport
Force Sensitive Resistors worden gebruikt in orthopedisch onderzoek voor drukdistributie. De Adafruit Round FSR (C3063-003) heeft een operationeel bereik van 0.1N tot 10N — voldoende voor foot pressure bij skateboarden.

## AI coaching
Externe focus instructies ("get closer to the board") zijn bewezen effectiever dan interne focus instructies ("bend your knees") — Wulf et al. (2010). Dit is geïmplementeerd in het coaching prompt van Claude.

---

# 4. MARKTANALYSE

## Marktgrootte
- Globale skateboardmarkt: $2.4B USD (2023), verwacht $3.6B in 2030
- 85 miljoen skaters wereldwijd
- Groei van 8.2% CAGR door streetwear trends en Olympic exposure (2020, 2024)

## Technologie in actiesport
- Smartboards: Segway, OneWheel
- Actiecamera analyse: GoPro
- Prestatiemeting: Catapult Sports (hoofdzakelijk teamsport)
- **Gat in de markt:** Geen enkel product combineert on-board sensoren + AI coaching voor skateboarden

## Prijspositie
- Doelgroep: tieners en jonge volwassenen (13-28 jaar)
- Bereidheid te betalen voor sport-tech: €15-40/maand (subscriptie)
- Hardware eenmalige kost: <€30 (ESP32 + sensoren + behuizing)

---

# 5. CONCURRENTIEANALYSE

| Product | Sensoren | AI Coaching | App | Prijs |
|---|---|---|---|---|
| **SK8SENSE** | IMU + FSR (4x) | Claude AI | React Native | €0 (prototype) |
| Boardriders App | Geen hardware | Nee | Video analyse | Gratis |
| GoPro + Quik | Camera | Nee | Video editing | €500+ |
| Carv (ski) | Voet sensoren | Ja (ski) | iOS/Android | €199 + abo |
| Trace (snowboard) | IMU | Statistieken | App | €149 |

**Conclusie:** SK8Sense is het enige product dat specifiek skateboard trick detectie combineert met AI-gebaseerde coaching via on-board hardware.

---

# 6. DOELGROEPANALYSE

## Primaire doelgroep
- **Leeftijd:** 14-25 jaar
- **Niveau:** Beginnend tot intermediate (< 2 jaar ervaring)
- **Motivatie:** Tricks willen leren zonder dure lessen
- **Frustratie:** Geen feedback op wat fout gaat
- **Tech-comfort:** Hoog — smartphone is verlengde van zichzelf

## Secundaire doelgroep
- Ouders die tools zoeken voor begeleide ontwikkeling
- Skate coaches die data willen bij training

## Inzichten uit observaties
- Skaters filmen zichzelf al (TikTok/Instagram) → ze willen zichzelf verbeteren
- Zelfstandig leren is cultuur in skateboarden → AI past hierin
- Externe feedback werkt beter dan technische instructies in skate cultuur

---

# 7. MOSCOW-ANALYSE

## Must Have
- ✅ BLE verbinding ESP32 ↔ app
- ✅ Realtime IMU data streaming (100Hz)
- ✅ Trick detectie: Ollie, Kickflip, Pop Shove-it
- ✅ Sessie opnemen + bewaren
- ✅ Gebruikersauthenticatie (Firebase)
- ✅ Live board visualisatie (pitch/roll)

## Should Have
- ✅ FSR druksensoren (4x: neus/hiel/teen/staart)
- ✅ AI coaching feedback (Claude Haiku)
- ✅ Profile met statistieken
- ✅ Sessie samenvatting
- ✅ Kalibratie van sensoren

## Could Have
- ✅ 3D skateboard visualisatie
- ✅ Leermodule met stap-voor-stap tricks
- ⬜ Video synchronisatie
- ⬜ Multiplayer/vrienden vergelijken

## Won't Have (voor MVP)
- ⬜ TensorFlow Lite on-device ML
- ⬜ FSR-gebaseerde trick detectie (FSR kwamen laat aan)
- ⬜ iOS build
- ⬜ Betaalsysteem

---

# 8. FUNCTIONELE ANALYSE

## Systeemoverzicht
```
[Skateboard]
    └── ESP32-S WROOM
        ├── MPU6050 (I2C: GPIO21/22)
        ├── FSR Nose (GPIO34)
        ├── FSR Heel (GPIO35)
        ├── FSR Toe (GPIO32)
        ├── FSR Tail (GPIO33)
        └── BLE 2.4GHz → [Smartphone]

[Smartphone App]
    ├── BLE Scanner + Verbinding
    ├── Sensor data parsing (JSON 100Hz)
    ├── Pitch/Roll berekening (atan2)
    ├── Trick detectie state machine
    ├── 3D board visualisatie
    ├── AI Coach (Claude API)
    └── Firebase (Auth + Firestore)
```

## BLE Data Protocol
```json
{
  "ax": -4.37,   // acceleratie X (m/s²)
  "ay": 0.40,    // acceleratie Y (m/s²)
  "az": 7.96,    // acceleratie Z (m/s²)
  "gx": -5.83,   // gyroscoop X (°/s)
  "gy": 1.34,    // gyroscoop Y (°/s)
  "gz": 0.56,    // gyroscoop Z (°/s)
  "trick": "none", // "none" | "ollie" | "kickflip" | "heelflip" | "bs_shuv" | "fs_shuv"
  "f1": 0,       // FSR neus (0-1023)
  "f2": 0,       // FSR hiel (0-1023)
  "f3": 0,       // FSR teen (0-1023)
  "f4": 0        // FSR staart (0-1023)
}
```

## Trick Detectie Algoritme (ESP32)
```
1. IDLE → als magnitude < 6.5 m/s² → AIRTIME
   - Reset peak tracking (peakGx, peakGy)
2. AIRTIME → track peak rotaties
   - peakGY > 160°/s → bs_shuv of fs_shuv
   - peakGX > 180°/s → kickflip of heelflip
   - anders → ollie
   - als magnitude > 15 m/s² (landing impact) → LANDING
3. LANDING → 400ms wachten → IDLE
```

## App Schermen
1. **Onboarding** — eerste launch, intro slides
2. **Login / Register** — Firebase Auth
3. **Home** — stats overview, quick scan CTA
4. **Connect** — BLE scan + verbinden
5. **Dashboard** — live sessie: 3D board, detectie feed, FSR bars
6. **Session Summary** — na sessie: stats + AI analyse
7. **Learning** — trick bibliotheek (3 tricks + coming soon)
8. **TrickIntro** — stap-voor-stap uitleg
9. **Practice** — oefenmodus met animaties
10. **Profile** — progressie, history, stats

---

# 9. PERSONA'S

## Persona 1: Kobe (16)
- **Bio:** Skater sinds 6 maanden, leert uit YouTube video's
- **Doel:** Zijn eerste kickflip landen
- **Frustratie:** "Ik zie niet wat er fout gaat"
- **Tech:** Snapchat, TikTok, films zichzelf al
- **Quote:** *"Als ik wist wat er mis gaat, zou ik het kunnen fixen"*

## Persona 2: Lars (22)
- **Bio:** 4 jaar skatender, intermediate level
- **Doel:** Consistentie verbeteren, beter worden voor street sessions
- **Frustratie:** "Ik land 7 van 10 ollies maar snap niet wanneer het fout gaat"
- **Tech:** Fitness tracker gebruiker, data-gedreven
- **Quote:** *"Cijfers liegen niet"*

## Persona 3: Elien (28)
- **Bio:** Skate coach, geeft les aan beginners in lokale skatepark
- **Doel:** Haar leerlingen objectieve feedback geven
- **Frustratie:** "Ik kan maar 1 leerling tegelijk observeren"
- **Tech:** Professioneel, zoekt tools die werken
- **Quote:** *"Als ik data had over elke poging, kon ik veel gerichter coachen"*

---

# 10. CUSTOMER JOURNEY

## Fase 1: Bewustzijn
- **Touchpoint:** Instagram ad, TikTok video van skater met data-overlay
- **Emotie:** Nieuwsgierigheid
- **Actie:** App downloaden

## Fase 2: Onboarding
- **Touchpoint:** Welkomstscherm, 4 intro slides
- **Emotie:** Opwinding, lichte verwarring (hardware?)
- **Actie:** Account aanmaken, hardware bestellen

## Fase 3: Hardware setup
- **Touchpoint:** Instructies in app (wiring diagram)
- **Emotie:** Frustratie (solderen is moeilijk), trots als het werkt
- **Actie:** ESP32 + sensoren monteren op board

## Fase 4: Eerste sessie
- **Touchpoint:** Dashboard met live data, eerste trick detectie
- **Emotie:** WOW moment — board ziet wat je doet
- **Actie:** Sessie opnemen, AI feedback lezen

## Fase 5: Progressie
- **Touchpoint:** Profile screen, sessiegeschiedenis, XP groei
- **Emotie:** Motivatie, competitiedrang
- **Actie:** Elke sessie opnemen, tricks verbeteren

## Fase 6: Aanbeveling
- **Touchpoint:** Gedetecteerde trick deelt op social media
- **Emotie:** Trots
- **Actie:** Vrienden aanraden

---

# 11. SYNTHESE TECHNISCH ONDERZOEK

## Hardware keuzes & motivatie

### ESP32-S WROOM 38-pin
- Gekozen voor ingebouwde BLE + WiFi
- 240MHz dual-core voldoende voor 100Hz IMU + JSON serialisatie
- I2C voor MPU6050, 4x ADC voor FSR, ruimte voor uitbreiding

**Probleem gevonden:** AMS1117 LDO regulator op NodeMCU heeft minimaal 4.5V nodig. LiPo geeft 3.7-4.2V → **BLE werkt niet op batterij zonder boost converter**. Oplossing: MT3608 boost converter (3.7V → 5V).

### MPU6050
- I2C op GPIO21 (SDA) / GPIO22 (SCL)
- Sample rate 100Hz via `Wire.setClock(100000)`
- ±8g accelerometer, ±500°/s gyroscoop
- **Probleem:** I2C verloor verbinding bij trilling → opgelost met `Wire.setClock(100000)` (lagere klok voor stabiliteit op perfboard)

### FSR 402 (Adafruit Round)
- Voltage divider: 3.3V → FSR → GPIO → 10kΩ → GND
- Raw ADC waarden: 0-4095 (12-bit)
- **Probleem 1:** Alle weerstanden naar SVP (GPIO36) gesoldeerd i.p.v. GND → kortsluiting tussen alle sensoren → opgelost
- **Probleem 2:** Enkele koude lassen → sensoren reageerden niet → opgelost door hersolleren
- Na correctie: alle 4 FSRs volledig geïsoleerd en functioneel

### NimBLE (BLE bibliotheek)
- Advertising naam "SK8Sense" initieel niet zichtbaar in scan (zat in scan response, niet advertisement packet)
- Opgelost door `pAdvertising->addServiceUUID()` correct te configureren
- App filtert nu op device naam

## Software keuzes & motivatie

### React Native + Expo
- Cross-platform voor iOS/Android
- Expo dev client voor BLE native modules
- **Nadeel:** expo-gl niet compatibel met RN 0.81.5 → 3D fallback naar WebView Three.js, daarna naar React Native Animated (meest stabiel)

### Trick detectie: firmware vs app
- ESP32 doet primaire detectie (airtime + rotatie) → betrouwbaarder door lagere latency
- App heeft secundaire state machine voor granulaire states (pop/airtime/landing)
- Beide systemen werken parallel

### Claude AI Coach
- Model: claude-haiku-4-5 (snel, goedkoop, voldoende voor 1-zin tips)
- Prompt engineering: externe focus instructies, skate cultuur taal
- API key lokaal opgeslagen (gitignored), nooit gecommit

---

# 12. WIREFRAMES (beschrijving Adobe XD)

## Scherm 1: Home
- Header: SK8SENSE logo + notificatie button
- Hero panel: Readiness Index (groot %) met PEAK chip
- Motion AI card met coaching bericht + CTA knop
- Stat grid: DETECTIONS / SESSIONS / ON-BOARD
- Latest session preview

## Scherm 2: Connect
- BLE scanner animatie (pulserende ringen)
- Device lijst met MAC adressen
- Connect knop per device
- Status: Scanning / Found / Connecting

## Scherm 3: Dashboard (Live Sessie)
- Top bar: timer groot (64px) + detectie counter
- Detection banner (oranje flash bij trick)
- 3D board viewer (pitch/roll live)
- IMU strip: AX/AY/AZ waarden
- FSR bars: NOSE/HEEL/TOE/TAIL
- Detection feed onderaan
- END SESSION knop

## Scherm 4: Learning
- Header: TRICKS + MVP chip
- 3 trick cards (Ollie/Kickflip/Pop Shuv-it) met ticked panels
- Coming soon grid met 6 vergrendelde tricks
- Motion AI roadmap banner

## Scherm 5: Profile
- Avatar + naam + email
- Stats grid: Sessions/Tricks/Time/Best
- Bar chart laatste sessies
- Trick breakdown met bars
- Sign out

---

# 13. MOCK-UPS (beschrijving Adobe XD)

## Design System: MIS v3 (Movement Intelligence System)
- **Stijl:** Neo-brutalist performance OS
- **Achtergronden:** 5 niveaus van void black (#0A0A0B → #202026)
- **Grid overlay:** 46px raster met 4% opacity
- **Ticked panels:** Oranje hoekkruisen op alle interactieve kaarten
- **RegStrip:** Technische metadata bovenaan elk scherm

## Kleurgebruik
| Element | Kleur |
|---|---|
| Background | #0A0A0B |
| Cards | #121215 |
| Accent / CTA | #FF6A3D |
| Success | #4CAF50 |
| Warning | #FFB020 |
| Danger | #FF4438 |
| Primary text | #ECECE8 |

## Typografisch systeem
- Display headings: Archivo 800 — UPPERCASE, letterSpacing -0.04em
- Technical labels: IBM Plex Mono 9px — UPPERCASE, letterSpacing 1.62
- Body text: Space Grotesk 13px — lineHeight 1.5

---

# 14. STIJLGIDS

*Zie `app/design-tokens.js` voor de actieve implementatie en `docs/design/design-tokens-reference.js` voor de referentie-export.*

## Kleurpalette
```js
ACCENT   = '#FF6A3D'  // signal orange
BG.base  = '#0A0A0B'  // void black
BG.b2    = '#121215'  // card surface
TEXT.t1  = '#ECECE8'  // primary
TEXT.t2  = '#8C8C92'  // secondary
TEXT.t3  = '#56565C'  // dimmed
LINE.dim = 'rgba(255,255,255,0.075)'
```

## Componenten
- **V3Ticked:** Panel met oranje hoekkruisen
- **V3RegStrip:** Technische header per scherm
- **V3SectionHead:** Sectieheaders met index + lijn
- **V3StatGrid:** Data grid met nummers
- **V3MotionAI:** AI coaching card
- **V3MotionTip:** Snelle tip met linkse accent border
- **V3Chip:** Status badges (default/live/solid)

## Buttons
- **Primary:** Accent achtergrond, UPPERCASE Archivo, ink kleur tekst
- **Ghost:** Transparant, border LINE.mid, witte tekst
- **Danger:** Rode border + tekst (end session)

## Iconen
- Ionicons 5 (geïntegreerd in Expo)
- Grootte: 14-28px afhankelijk van context

---

# 15. GEBRUIKERSDOCUMENTATIE

## Hardware installatie

### Benodigdheden
- ESP32-S WROOM NodeMCU 38-pin
- MPU6050 gyroscoop module
- 4× Adafruit Round FSR (model 402)
- 4× 10kΩ weerstand
- TP4056 LiPo oplader module
- MT3608 boost converter (3.7V → 5V)
- LiPo batterij 3.7V min. 500mAh
- Schuifschakelaar (SS12D00G2)
- Perfboard + soldeerbout

### Bedrading

**MPU6050:**
```
ESP32 3.3V → MPU6050 VCC
ESP32 GND  → MPU6050 GND
ESP32 GPIO21 → MPU6050 SDA
ESP32 GPIO22 → MPU6050 SCL
```

**FSR sensoren (voltage divider per sensor):**
```
ESP32 3.3V → FSR poot 1
FSR poot 2 → GPIO34 (nose) / GPIO35 (heel) / GPIO32 (toe) / GPIO33 (tail)
GPIO pin   → 10kΩ weerstand → GND
```

**Voeding:**
```
Batterij + → TP4056 B+
Batterij - → TP4056 B-
TP4056 OUT+ → MT3608 IN+
TP4056 OUT- → MT3608 IN-
MT3608 OUT+ (ingesteld op 5V) → Schakelaar → ESP32 5V/VIN pin
MT3608 OUT- → ESP32 GND
```

### App installatie
1. Download SK8Sense APK van [repository]
2. Installeer op Android (Settings → Unknown sources)
3. Registreer met email + wachtwoord
4. Ga naar Board → Scan for Board

### Verbinden
1. Zet het board aan (schakelaar)
2. Open de app → Board tab
3. Tap "SCAN FOR BOARD"
4. Selecteer "SK8Sense" uit de lijst
5. Tap "Connect"
6. Dashboard opent automatisch

### Kalibratie
1. Leg het board plat op de grond
2. Tap "◎ CALIBRATE" in het dashboard
3. PITCH en ROLL waarden resetten naar 0°

### Sessie opnemen
1. Tap "▶ START SESSION"
2. Ga skaten
3. Tricks worden automatisch gedetecteerd
4. Tap "■ END SESSION"
5. Sessie samenvatting + AI feedback verschijnt

---

# 16. ONDERHOUDSDOCUMENTATIE

## Repository structuur
```
SK8Sense/
├── firmware/                  # ESP32 Arduino C++ code
│   └── src/main.cpp           # Hoofdfirmware
├── app/                       # React Native Expo app
│   ├── App.js                 # Root met font loading
│   ├── design-tokens.js       # Compleet design systeem
│   ├── components/
│   │   ├── V3Shared.js        # Gedeelde v3 componenten
│   │   └── LiveBoardViewer.js # 3D board visualisatie
│   ├── screens/               # Alle app schermen
│   ├── store/                 # Zustand state stores
│   │   ├── bleStore.js        # BLE verbinding
│   │   ├── sessionStore.js    # Sessie data
│   │   ├── authStore.js       # Firebase auth
│   │   └── trickStore.js      # Trick bibliotheek
│   ├── services/
│   │   └── aiCoach.js         # Claude API integratie
│   └── config/
│       ├── firebase.js        # Firebase config (vul in)
│       └── ai.js              # Anthropic API key (gitignored)
├── hardware/enclosure/        # STL/UFP bestanden voor de behuizing
├── docs/                      # Documentatie, proces, screenshots en testlogs
└── archive/                   # Oude geneste kopie, niet actief
```

## Firmware aanpassen

### Drempelwaarden wijzigen
In `firmware/src/main.cpp`:
```cpp
#define AIRTIME_MAG_MAX   6.5f   // Lager = gevoeliger voor airtime
#define LAND_MAG_MIN      15.0f  // Lager = detecteert zachte landingen
#define KICK_THRESHOLD    180.0f // Lager = minder flip nodig voor kickflip
#define SHUV_THRESHOLD    160.0f // Lager = minder spin voor shove-it
```

### Nieuwe trick toevoegen
In `detectTrick()` functie:
```cpp
} else if (abs(peakGx) > 350.0f && abs(peakGy) > 350.0f) {
    detectedTrick = "varial_flip"; // nieuw
}
```

### Firmware uploaden
1. PlatformIO installeren in VS Code
2. BOOT knop ingedrukt houden op ESP32
3. Terminal: `pio run --target upload`

## App aanpassen

### Design tokens wijzigen
Bewerk `app/design-tokens.js`:
```js
export const ACCENT = '#FF6A3D'; // Verander hier voor nieuw accent
```

### Nieuwe trick toevoegen aan learning
In `screens/LearningScreen.js`, voeg toe aan `FEATURED` array:
```js
{
  id: 'heelflip',
  name: 'HEELFLIP',
  difficulty: 'INTERMEDIATE',
  diffColor: '#2196F3',
  category: 'FLATGROUND',
  code: 'T.04',
  steps: 5,
  description: 'Kick out with your heel and let the board flip.',
},
```

### AI coaching aanpassen
In `services/aiCoach.js`, pas de prompt aan:
```js
const prompt = `You are a pro skateboarding coach...`
```

### Firebase configuratie
Vul in `config/firebase.js`:
```js
const firebaseConfig = {
  apiKey: "YOUR_API_KEY",
  authDomain: "YOUR_PROJECT.firebaseapp.com",
  projectId: "YOUR_PROJECT_ID",
  ...
};
```

### Anthropic API key
Zet de key lokaal in `app/.env.local` (is gitignored):
```env
EXPO_PUBLIC_ANTHROPIC_API_KEY=your_anthropic_key_here
```

De app leest die waarde via `process.env.EXPO_PUBLIC_ANTHROPIC_API_KEY`.

## Afhankelijkheden updaten
```bash
cd app
npx expo install         # Expo-compatibele versies
npm install              # Overige packages
```

## Bekende limitaties
- BLE werkt niet zonder MT3608 boost converter op batterij (3.7V te laag voor AMS1117 regulator)
- iOS vereist Apple Developer account ($99/jaar) voor dev build
- Three.js 3D viewer werkt enkel in WebView (expo-gl incompatibel met RN 0.81.5)

---

# 17. TESTVERSLAG

## Testmethode
Iteratief testen tijdens ontwikkeling: hardware tests via Serial Monitor (PlatformIO), app tests via Expo dev client op Android (Samsung A98G).

---

## Test 1: MPU6050 I2C verbinding

| | |
|---|---|
| **Datum** | April/Mei 2026 |
| **Verwacht** | `MPU6050 connected OK` in Serial Monitor |
| **Resultaat** | `MPU6050 connection FAILED` bij eerste test op perfboard |
| **Oorzaak** | GND van gyroscoop verbonden via weerstand (spanning op GND) |
| **Oplossing** | GND direct (geen weerstand) verbonden |
| **Status** | ✅ Opgelost |

---

## Test 2: FSR sensoren kortsluiting

| | |
|---|---|
| **Datum** | Mei 2026 |
| **Verwacht** | Elke sensor reageert onafhankelijk |
| **Resultaat** | Heel en toe gingen altijd samen op 4095 |
| **Oorzaak** | Alle weerstanden naar SVP (GPIO36) i.p.v. GND → gedeeld referentiepunt |
| **Oplossing** | Alle weerstanden naar GND verplaatst |
| **Status** | ✅ Opgelost |

---

## Test 3: FSR sensoren koude lassen

| | |
|---|---|
| **Datum** | Mei 2026 |
| **Verwacht** | Alle 4 FSRs reageren bij druk |
| **Resultaat** | Alle FSRs lezen 0, ook bij druk |
| **Oorzaak** | 3.3V verbinding losgeraakt bij hersolleren van weerstanden |
| **Oplossing** | 3.3V opnieuw gesoldeerd, alle lassen glanzend gemaakt |
| **Status** | ✅ Opgelost |

---

## Test 4: FSR individuele werking

| Sensor | GPIO | Verwacht | Resultaat | Status |
|---|---|---|---|---|
| Nose | 34 | ~3900 bij druk, 0 in rust | ✅ ~4095 bij druk | ✅ |
| Heel | 35 | ~3900 bij druk, 0 in rust | ✅ ~4095 bij druk | ✅ |
| Toe | 32 | ~3900 bij druk, 0 in rust | ✅ ~4095 bij druk | ✅ |
| Tail | 33 | ~3900 bij druk, 0 in rust | ✅ ~4095 bij druk | ✅ |

---

## Test 5: BLE trick detectie

| Trick | Verwacht | Resultaat | Status |
|---|---|---|---|
| Ollie | `trick: "ollie"` bij airtime | ✅ Correct gedetecteerd | ✅ |
| Kickflip | `trick: "kickflip"` bij GX > 180°/s | ✅ Correct | ✅ |
| Heelflip | `trick: "heelflip"` bij GX < -180°/s | ✅ Correct | ✅ |
| BS Shove-it | `trick: "bs_shuv"` bij GY > 160°/s | ✅ Correct | ✅ |
| Pop (nep) | `trick: "none"` als geen airtime | ✅ Geen false positive | ✅ |

---

## Test 6: BLE advertentie op batterij

| | |
|---|---|
| **Datum** | Mei 2026 |
| **Verwacht** | ESP32 zichtbaar in BLE scan op batterij |
| **Resultaat** | Niet zichtbaar — LED dim, BLE adverteert niet correct |
| **Oorzaak** | AMS1117 LDO op NodeMCU vereist min. 4.5V input; LiPo geeft 3.7V → regulator in dropout onder BLE piekstroom |
| **Oplossing** | MT3608 boost converter (3.7V → 5V) besteld |
| **Status** | ⏳ In afwachting hardware |

---

## Test 7: Live pitch/roll in app

| | |
|---|---|
| **Datum** | Mei 2026 |
| **Verwacht** | PITCH/ROLL waarden veranderen bij bewegen van board |
| **Resultaat** | Initieel alles 0.0° ondanks verbinding |
| **Oorzaak** | Stale closure in BLE callback — `handleIncomingData` gebruikte oude `setPitch/setRoll` referenties |
| **Oplossing** | Pitch/roll berekend direct van `sensorData` in render (geen extra state) + `boardRef.current.update()` op 100Hz |
| **Status** | ✅ Opgelost — PITCH -21.4° / ROLL 26.7° werken correct |

---

## Test 8: AI coaching feedback

| | |
|---|---|
| **Datum** | Mei 2026 |
| **Verwacht** | AI geeft relevante tip na trick detectie |
| **Resultaat** | Claude Haiku antwoord in < 2s met externe focus tip |
| **Voorbeeld output** | *"Stay over the bolts — your back foot's drifting on landing."* |
| **Status** | ✅ Functioneel |

---

## Samenvatting testresultaten

| Component | Geteste features | Geslaagd | Gefaald | In behandeling |
|---|---|---|---|---|
| Hardware - MPU6050 | I2C verbinding, pitch/roll | ✅ | - | - |
| Hardware - FSR | 4× isolatie, drukrespons | ✅ | - | - |
| Hardware - Batterij | BLE op batterij | - | ❌ | ⏳ boost converter |
| App - BLE | Scan, verbinden, data | ✅ | - | - |
| App - Detectie | 5 tricks | ✅ | - | - |
| App - Visualisatie | Pitch/roll animatie | ✅ | - | - |
| App - AI coach | Tip generatie | ✅ | - | - |
| App - Sessies | Opnemen, opslaan, laden | ✅ | - | - |

---

# BRONNEN

- Schmidt, R.A. & Lee, T.D. (2011). *Motor Control and Learning: A Behavioral Emphasis* (5th ed.). Human Kinetics.
- Wulf, G., Shea, C. & Lewthwaite, R. (2010). Motor skill learning and performance: a review of influential factors. *Medical Education*, 44(1), 75–84.
- Tang, W., et al. (2020). Skateboard Trick Recognition Using Inertial Measurement Units. *IEEE Sensors Journal*, 20(14).
- Adafruit FSR 402 Datasheet. adafruit.com
- ESP32 Technical Reference Manual. Espressif Systems.
- NimBLE-Arduino Documentation. h2zero/NimBLE-Arduino.
- Expo Documentation. docs.expo.dev
- React Native BLE PLX Documentation. dotintent/react-native-ble-plx
- Anthropic API Documentation. docs.anthropic.com

---

*SK8Sense · Movement Intelligence System v0.9 · Kylian Algoet · 2026*

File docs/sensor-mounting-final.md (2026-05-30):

# SK8SENSE
## Research Document — Sensor Mounting & Protection — FINALE VERSIE
### Onderzoek naar plaatsing, bescherming en testmethodologie + Evaluatie na prototype
**Kylian Algoet**
**Multimedia & Creative Technology**
**Final Work — April–Mei 2026**

---

## 1. Inleiding

Dit document onderzoekt de drie meest kritieke fysieke aspecten van het SK8Sense hardware prototype: waar de sensormodule geplaatst wordt op het skateboard, hoe deze beschermd wordt tegen de extreme omstandigheden van skaten, en hoe de installatie systematisch getest kan worden voordat hij meegenomen wordt naar de straat.

Dit document combineert het oorspronkelijke onderzoek (uitgevoerd vóór de bouw) met de definitieve bevindingen na realisatie van het prototype. Secties gemarkeerd met ⚠️ bevatten aanpassingen of nieuwe inzichten die voortkwamen uit de praktijk.

### 1.1 Onderzoeksvragen

1. Waar op het skateboard moet de sensormodule geplaatst worden voor optimale datakwaliteit en minimale schade?
2. Welke beschermingsstrategieën garanderen dat de sensor functioneert tijdens normaal én abnormaal skategebruik?
3. Hoe kunnen we systematisch testen of de mounting setup geslaagd is voordat we live data verzamelen?
4. Welke materialen en componenten zijn nodig om bovenstaande te realiseren binnen het tijds- en budgetkader van het eindwerk?

---

## 2. Plaatsing op het skateboard

### 2.1 Anatomie van een skateboard deck

Een standaard skateboard deck heeft drie functioneel verschillende zones: nose (voorkant, omhoog gekromd), middendeel (vlak, tussen de trucks), en tail (achterkant, omhoog gekromd). De trucks zijn de metalen ophangingen waaraan de wielen vastzitten.

De sensor heeft drie eisen aan zijn plaatsing:
- **Mechanisch:** minimale impact tijdens landings en grindjes
- **Sensorisch:** zo dicht mogelijk bij het zwaartepunt van het board voor representatieve bewegingsdata
- **Praktisch:** niet in de weg bij het skaten, geen verandering aan het skate-gevoel

### 2.2 Vergelijking van mogelijke plaatsingen

| Locatie | Mechanisch | Sensorisch | Praktisch | Verdict |
|---|---|---|---|---|
| Onder nose | Slecht — krast bij elke nose grind | Slecht — randzone, asymmetrische data | Slecht — dicht bij voet | Verworpen |
| Onder tail | Slecht — krast bij elke pop en grind | Slecht — randzone, asymmetrisch | Slecht — voet komt erop | Verworpen |
| Bovenop deck (onder griptape) | Matig — niet in directe impact zone | Goed — meet board beweging direct | Slecht — verandert grip, drukt door | Verworpen voor MPU, wel voor FSR |
| **Onder deck, midden tussen trucks** | **Goed — beschermd door trucks aan weerszijden** | **Uitstekend — exact zwaartepunt board** | **Goed — geen voetcontact mogelijk** | **Gekozen** |

**Conclusie plaatsing IMU module:**
De sensormodule (ESP32 + MPU6050 + batterij) wordt gemonteerd onder het deck, exact in het midden tussen de twee trucks. De trucks fungeren als natuurlijke schokdempers en de centrale positie garandeert representatieve bewegingsdata.

### 2.3 Plaatsing van de FSR druksensoren

De FSR druksensoren zitten bovenop het deck, onder het griptape. Vier strategische meetpunten op basis van skate-biomechanica:

| Positie | GPIO | Functie | Wat detecteert het |
|---|---|---|---|
| FSR 1: Nose pocket | GPIO34 | Voorkant van voorste voet | Nose presses, manuals, kickflip catch |
| FSR 2: Heel side | GPIO35 | Heel zijde voorste voet | Kickflip flick (heel zijde druk) |
| FSR 3: Toe side | GPIO32 | Toe zijde voorste voet | Heelflip flick (toe zijde druk) |
| FSR 4: Tail pocket | GPIO33 | Achterste voet pop zone | Pop kracht voor ollie en flips |

### 2.4 ⚠️ Bevindingen na prototype — Plaatsing in praktijk

De theoretisch gekozen plaatsing bleek correct. De centrale mounting onder het deck bleef intact gedurende alle testsessies. De FSR-sensoren werden direct op het deck bevestigd via de aansluitdraden, die door de behuizing gaan naar de elektronica binnenin.

**Aanpassing bedrading:**
In de originele planning was voorzien om kanaaltjes in het hout te frezen voor de FSR-draden. In de praktijk bleek dit niet nodig: de draden zijn dun genoeg (30AWG soepele silicone draad) om langs de zijkanten van de behuizing te lopen zonder het skate-gevoel te beïnvloeden.

---

## 3. Bescherming tegen schade

### 3.1 Bedreigingen analyse

| Bedreiging | Frequentie | Risico voor sensor | Mitigatie strategie |
|---|---|---|---|
| Landing schokken (3–10G) | Bij elke trick | Loszittende soldeerpunten, scheuren in PCB | Foam demping in case, lijm op verbindingen |
| Vibraties tijdens rijden | Continu | Loskomende draadjes, ruis in data | Heat shrink op draden, software low-pass filter |
| Grindjes over metaal | Tricks zoals 50–50, board slide | Krassen op behuizing, mogelijk doorslijten | PLA behuizing, centrale plaatsing |
| Vallen op zijn kop | Bij mislukte tricks | Direct impact op behuizing | Afgeronde hoeken case, dikte 2mm wanden |
| Regen of vochtige grond | Onverwacht | Kortsluiting, batterij schade | Gesloten case, USB poort dichtmaken |
| Stof en zand | Outdoor sessies | Indringen in connectors | Gesloten case, niet-poreus materiaal |
| UV en hitte (zomer) | Lange sessies | Plastic verzwakt, batterij degradeert | Geen langdurige blootstelling prototype |
| Trillen los | Na maanden | Sensor valt eraf tijdens skaten | Schroeven door truck mounting |

### 3.2 Beschermingsstrategie in lagen

#### Laag 1: PLA behuizing

| Materiaal | Sterkte | Flexibiliteit | UV bestand | Print moeilijkheid | Verdict |
|---|---|---|---|---|---|
| **PLA** | Hoog stijf | Bros — barst bij impact | Slecht | Makkelijk | **Gekozen (prototype)** |
| ABS | Sterk | Flexibel | Goed | Moeilijk (warpt) | Alternatief voor productie |
| PETG | Sterk | Flexibel | Goed | Makkelijk | Aanbevolen voor v2 |
| TPU (rubber) | Zacht | Zeer flexibel | Matig | Moeilijk | Evt. voor dempende pads |

> **Nota:** In de originele planning was PETG voorzien. Voor het prototype werd PLA gebruikt vanwege beschikbaarheid op de schoolprinter. PLA is voldoende voor prototype-doeleinden maar een productieversie zou PETG of ABS gebruiken voor betere slagvastheid.

**Specificaties van de behuizing:**
- Wanddikte: 2mm
- Centrale plaatsing op het deck, tussen de trucks
- Schakelaar toegankelijk aan de zijkant
- Opening voor micro-USB oplading

#### Laag 2: Mechanische bevestiging via truck bouten

De sensormodule wordt bevestigd via de truck bolt-posities. Dit principe is beproefd: skateboard riser pads worden al decennia op dezelfde manier gemonteerd.

#### Laag 3: Software resilience

- Auto-reconnect bij BLE-verbindingsverlies
- Watchdog timer op de ESP32 — herstart automatisch bij crash
- Local data buffer in app — geen dataverlies bij korte verbindingsdrop
- Batterijmonitoring via GPIO36 (ADC voor spanningsmeting)
- Outlier detectie — een onverwachte 50G piek is een crash, geen trick

### 3.3 ⚠️ Bevindingen na prototype — Bescherming in praktijk

De PLA-behuizing bleef intact gedurende alle testsessies. De mounting via tape en foam bleek voldoende voor statische tests maar voor een productieversie blijven truck-bouten de voorkeur hebben.

**Toevoeging MT3608 boost converter:**
Een component die niet voorzien was in de originele beschermingsstrategie: de MT3608 DC-DC step-up converter. Deze verhoogt de 3.7V van de LiPo naar 5V voor de ESP32. Dit component wordt intern in de behuizing geplaatst naast de TP4056 lader. De extra warmteontwikkeling van de boost converter (~10% warmteverlies) is verwaarloosbaar bij de huidige stroomconsumptie.

---

## 4. Testmethodologie

### 4.1 Fase 1 — Bench tests (zonder skaten)

| Test | Methode | Slaag criterium | Resultaat |
|---|---|---|---|
| Boot test | Sensor inschakelen, LED en BLE controleren | Status actief binnen 3s, app vindt sensor | ✅ `MPU6050 OK` + `BLE advertising started` |
| BLE bereik test | App verbinden vanaf 1, 3, 5m | Stabiele connectie tot 5m minimum | ✅ Stabiel tot 8m in open ruimte |
| Sample rate test | 100Hz data ontvangen voor 60s, packet loss meten | <5% packet loss | ✅ <2% packet loss |
| Batterij test | Volledig opgeladen sensor laten streamen | Min. 4 uur continue streaming | ✅ 6+ uur op 2000mAh LiPo |
| Druk test FSR | Met vinger op elke FSR drukken | Elk FSR reageert onafhankelijk | ✅ Alle 4 volledig geïsoleerd na correcties |
| Schud test | Sensor handmatig schudden in alle richtingen | Accelerometer + gyroscoop reageren correct | ✅ Pitch/roll reageren live in app |

### 4.2 ⚠️ Aanvullende bench tests — Voortgekomen uit problemen

De volgende tests werden niet voorzien maar werden noodzakelijk door ontdekte problemen:

**FSR isolatietest:**
Na de ontdekking van de kortsluitingsfout (alle weerstanden naar SVP i.p.v. GND), werd systematisch getest of elke FSR onafhankelijk reageerde. Test protocol:
1. Druk uitsluitend op sensor X
2. Controleer dat alleen sensor X een waarde >100 toont
3. Controleer dat alle andere sensoren 0 blijven
4. Herhaal voor alle 4 sensoren

Resultaat: alle 4 sensoren volledig geïsoleerd na correcties.

**Batterij + BLE test:**
Na de ontdekking van het voltageprobleem (AMS1117 LDO heeft 4.5V nodig, LiPo geeft 3.7V) werd specifiek getest of BLE correct adverteert op batterijspanning. Test protocol:
1. USB loskoppelen, overschakelen op batterij
2. Serial Monitor open houden: verifieer `SK8Sense BLE advertising started`
3. Scan met telefoon: verifieer apparaat verschijnt in lijst
4. Verbinden: verifieer stabiele datastream

Resultaat na toevoeging MT3608 boost converter: ✅ BLE werkt stabiel op batterij.

### 4.3 Fase 2 — Drop tests (gecontroleerde schade simulatie)

> **Status:** Gedeeltelijk uitgevoerd — volledige drop test protocol niet afgerond voor prototype 1 vanwege tijdsbeperkingen. Bench tests en field tests wel volledig uitgevoerd.

| Test | Methode | Slaag criterium | Resultaat |
|---|---|---|---|
| Lichte drop | Sensor vallen vanaf 30cm | Geen schade, blijft functioneren | ✅ Uitgetest |
| Pop simulatie | Board tail slaan op tafel (10×) | Geen interne loskoppeling | ✅ Geen loskoppeling |
| Medium drop | Vanaf 80cm | Geen schade | ⏳ Niet getest in dit prototype |
| Land simulatie | Board vanaf 30cm laten vallen (5×) | Geen schade | ⏳ Gepland voor v2 |

### 4.4 Fase 3 — Field tests (echte skate sessies)

| Niveau | Activiteit | Slaag criterium | Resultaat |
|---|---|---|---|
| **A: Statische test** | Board vasthouden en bewegen, sensoren testen | Alle 4 FSR reageren, pitch/roll correct | ✅ Volledig functioneel |
| **B: Basis beweging** | Board bewegen, kantelen, neus/staart oprichten | IMU data correct, BLE stabiel | ✅ Pitch -21.4°, Roll 26.7°, Impact 9.2 correct |
| **C: Volledige sessie** | In de lucht gooien met rotaties | Trick detectie via gyroscoop | ✅ Kickflip/ollie/shove-it gedetecteerd |

**Gemeten sensorwaarden tijdens tests:**
- Rust (plat): AX ≈ –4.38, AY ≈ 0.40, AZ ≈ 7.96 m/s² (zwaartekracht correct georiënteerd)
- Gyroscoop drift: <0.5°/s bij stilstand — acceptabel voor korte trick-detecties
- FSR ruisverdieping: ~300 ADC units op losgekoppelde pinnen — gefilterd in software (threshold 300)

---

## 5. Componentenkeuze — Evaluatie na realisatie

### 5.1 Microcontroller: ESP32-S WROOM 38-pins ✅

**Oorspronkelijke keuze bevestigd.** BLE, 18 ADC-pinnen en Arduino IDE-compatibiliteit bewezen zich correct.

**Aanvulling:** Het breadboard-prototype werkte vlekkeloos. De overgang naar perfboard vereiste extra zorg bij solderen maar leverde een stabielere verbinding op.

**Kritisch leerpunt:** De AMS1117 LDO-spanningsregelaar op de NodeMCU vereist minimaal 4.5V input — dit was niet voorzien en vereiste de toevoeging van een MT3608 boost converter.

### 5.2 Bewegingssensor: MPU6050 (GY-521 module) ✅

**Oorspronkelijke keuze bevestigd.** 6-axis voldoende voor trick detectie.

**Aanvulling:** I2C-kloksnelheid teruggebracht naar 100kHz voor stabiliteit op perfboard (`Wire.setClock(100000)`). Gyroscoop-drempelwaarden empirisch vastgesteld: kickflip >180°/s, shove-it >160°/s.

### 5.3 Drukstrips: FSR 12mm rond ✅

**Oorspronkelijke keuze bevestigd.** Alle 4 zones functioneel na correctie van bedradingsfouten.

**Kritisch leerpunt:** Alle 10kΩ pull-down weerstanden moeten naar GND, nooit naar een ADC-pin zoals SVP (GPIO36).

### 5.4 Voeding: LiPo + TP4056 ⚠️ Aangepast

**Aanpassingen t.o.v. oorspronkelijk plan:**

| Parameter | Origineel gepland | Definitief gebruikt | Reden |
|---|---|---|---|
| LiPo capaciteit | 1000mAh | **2000mAh** | Grotere marge, langere runtime |
| USB connector | USB-C | **Micro-USB** | Beschikbaarheid TP4056 module |
| Boost converter | Niet voorzien | **MT3608 toegevoegd** | AMS1117 vereist 4.5V min. |
| Runtime | 6–8 uur geschat | **6+ uur bevestigd** | ✅ |

---

## 6. Definitieve componentenlijst

| # | Component | Aantal | Status |
|---|---|---|---|
| 1 | NodeMCU ESP32-S WROOM 38-pins | 2 | ✅ Beide operationeel |
| 2 | MPU6050 GY-521 | 2 | ✅ 1 in gebruik, 1 backup |
| 3 | Adafruit FSR 402 round 12mm | 5 | ✅ 4 in gebruik, 1 backup |
| 4 | LiPo 3.7V 2000mAh (103450) | 2 | ✅ 1 in gebruik |
| 5 | TP4056 micro-USB lader | 2 | ✅ Werkend |
| 6 | **MT3608 boost converter (nieuw)** | **2** | **✅ Kritisch voor BLE op batterij** |
| 7 | SS12D00G2 schuifschakelaar | 3 | ✅ 1 gemonteerd |
| 8 | 10kΩ weerstanden | 10 | ✅ |
| 9 | Soepele silicone draad 30AWG | 1 set | ✅ |
| 10 | Krimpkous assortiment | 1 doos | ✅ |
| 11 | Perfboard | 2 | ✅ Gesoldeerd |
| 12 | 3D-geprinte PLA behuizing | 1 | ✅ Gemonteerd |
| 13 | Breadboard 830-gaats | 1 | Gebruikt voor initieel prototyping |

**Totale gerealiseerde kost:** circa €130–145, inclusief niet-geplande MT3608 converters.

**Via school verkregen:**
- Soldeerbout en helping hands — clusterlokaal
- 3D-printer en PLA filament — campus print room

---

## 7. Conclusie

De fysieke realisatie van het SK8Sense prototype bevestigt grotendeels de oorspronkelijke onderzoeksconclusies, met twee kritieke aanpassingen die voortkwamen uit de praktijk:

**Wat klopte uit het oorspronkelijk onderzoek:**
- ✅ Centrale mounting onder het deck tussen de trucks is de juiste plaatsing
- ✅ FSR-sensoren onder griptape detecteren voetdruk betrouwbaar
- ✅ Gelaagde bescherming (behuizing + software) werkt in praktijk
- ✅ Systematische testfasen (bench → field) identificeerden problemen vroeg

**Wat niet voorzien was:**
- ⚠️ **MT3608 boost converter noodzakelijk** — de AMS1117 LDO op de ESP32 NodeMCU vereist 4.5V, LiPo geeft slechts 3.7V → BLE werkte niet op batterij zonder boost
- ⚠️ **FSR-bedrading kritisch** — alle pull-down weerstanden naar GND, niet naar ADC-pinnen; een fout hier zorgt voor volledige cross-talk tussen sensoren
- ⚠️ **I2C kloksnelheid** — 400kHz (standaard) is instabiel op perfboard; 100kHz elimineert alle fouten

Het prototype demonstreert dat een functionerende, draagbare sensormodule voor skateboard trick detectie haalbaar is binnen het tijdsframe en budget van een Final Work project, mits het testproces rigoureus wordt uitgevoerd en problemen systematisch worden gedocumenteerd en opgelost.

---

*SK8Sense · Sensor Mounting Research · Kylian Algoet · MCT · 2025–2026*

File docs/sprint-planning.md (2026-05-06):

# SK8Sense — Tweewekelijkse Sprint Planning

---

## Sprint 1 — MVP1
**Periode:** 21 april – 4 mei 2026
**MVP doel:** Werkende BLE verbinding tussen ESP32 en Android app met gesimuleerde trick detectie

### Deeltaken
- PlatformIO project opzetten voor ESP32
- BLE advertising en NOTIFY characteristic implementeren
- Gesimuleerde sensordata state machine (ollie, kickflip, heelflip)
- React Native app scaffolding met Expo
- BLE scan + connect flow met Android runtime permissions
- Live dashboard met sensordata (10Hz throttle)
- Session flow: start/stop, timer, trick feed
- SessionSummaryScreen en HistoryScreen
- Coaching tips + pulse animatie na trick detectie
- Onboarding screen (4 slides)
- Standalone APK via EAS Build (geen laptop nodig voor demo)

### Status
Volledig afgerond. Echte BLE verbinding tussen ESP32 en Xiaomi Redmi Note 13 Pro+ werkt.
Sensordata is gesimuleerd omdat MPU6050 en FSR sensoren toekomen op 5 mei 2026.

---

## Sprint 2 — MVP2
**Periode:** 5 mei – 18 mei 2026
**MVP doel:** Echte sensordata van MPU6050 en FSR op het skateboard, eerste echte trick detectie op basis van drempelwaarden

### Deeltaken
- MPU6050 aansluiten via I2C (SDA pin 21, SCL pin 22)
- FSR sensoren aansluiten (GPIO 32, 33, 34, 35)
- Firmware updaten: echte ax/ay/az/gx/gy/gz uitlezen op 100Hz
- Firmware updaten: FSR waarden uitlezen voor tail press detectie
- Drempelwaarden calibreren voor ollie (tail press + airtime > 100ms)
- Drempelwaarden calibreren voor kickflip (GX > 300 graden/s) en heelflip (GX < -300 graden/s)
- Power circuit bouwen: LiPo batterij + TP4056 lader + slide switch + ESP32
- App: sensordata grafiek toevoegen aan dashboard
- Eerste echte trick detectie testen op skateboard

---

## Sprint 3 — MVP3
**Periode:** 19 mei – 1 juni 2026
**MVP doel:** TFLite classificatie model dat tricks detecteert met hogere betrouwbaarheid dan drempelwaarden

### Deeltaken
- Trainingsdata verzamelen: minimum 50 pogingen per trick opnemen als CSV
- Data labelen en preprocessing pipeline schrijven
- TFLite model trainen op tijdreeksdata van de IMU sensor
- Model converteren naar .tflite formaat
- Model integreren in React Native app voor on-device inferentie
- Confidence score tonen in de app
- Valse positieven filteren (minimum airtime, minimum pop kracht)
- Pop detectie toevoegen als apart niveau
- Hardware: ESP32 definitief monteren op skateboard

---

## Sprint 4 — MVP4
**Periode:** 2 juni – 15 juni 2026
**MVP doel:** Volledig afgewerkt eindproduct met cloud opslag en uitgebreide coaching

### Deeltaken
- Firebase project opzetten (Firestore + Authentication)
- Sessies opslaan in de cloud
- Gebruikersprofiel aanmaken (naam, level, statistieken)
- Progressie over tijd visualiseren via grafieken
- Shove-it detectie toevoegen (180 graden Y-as rotatie)
- Uitgebreidere coaching tips op basis van sensorpatronen
- UI polish: animaties, overgangen, volledige dark mode
- Productie APK bouwen en testen
- Eindpresentatie voorbereiden

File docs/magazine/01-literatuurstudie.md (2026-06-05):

# Literatuurstudie — SK8Sense

> **Nota voor finalisatie:** De bronnen in dit document verwijzen naar reële onderzoeksdomeinen en gevestigde werken. Controleer elke citatie (auteur, jaartal, exacte titel) in Google Scholar of de bibliotheekcatalogus vóór indiening, en vul paginanummers aan waar nodig.

## Inleiding

Om een onderbouwde, technologisch haalbare skatecoach te ontwikkelen, werd literatuuronderzoek gevoerd binnen vier domeinen die rechtstreeks de ontwerpkeuzes van SK8Sense bepalen:

1. **Draagbare bewegingssensoren (IMU) in sport** — kan beweging betrouwbaar gemeten worden?
2. **Bewegingsherkenning uit sensordata** — hoe herken je een trick (regelgebaseerd vs. machine learning)?
3. **Motorisch leren en feedback** — welke soort feedback laat skaters sneller leren?
4. **Gamification en motivatie** — hoe houd je gebruikers betrokken?

De bevindingen verklaren waarom SK8Sense werkt zoals het werkt: een ESP32 met IMU en druksensoren, regelgebaseerde trickdetectie op het toestel, en AI-gegenereerde coaching in een gemotiveerde, gamified interface.

---

## 1. Draagbare bewegingssensoren (IMU) in sport

Inertial Measurement Units (IMU's) — sensoren die versnelling (accelerometer) en rotatiesnelheid (gyroscoop) meten — zijn de afgelopen twee decennia de standaard geworden voor bewegingsanalyse in sport. Waar bewegingsanalyse vroeger optische motion-capture-systemen in een labo vereiste, maakt de daling van prijs en formaat van MEMS-sensoren het mogelijk om beweging "in het veld" te meten.

Onderzoek binnen *Human Activity Recognition* (HAR) toont consistent aan dat een combinatie van accelerometer- en gyroscoopdata voldoende discriminerend vermogen heeft om complexe, cyclische en explosieve bewegingen te onderscheiden. In boardsporten (snowboarden, surfen, skateboarden) is de relevante beweging kort en hoog-dynamisch: een trick duurt minder dan een seconde en bevat zowel translatie (de pop, de landing-impact) als rotatie (de flip, de spin). Een 6-assige IMU vangt beide.

**Relevantie voor SK8Sense.** De gekozen MPU6050 levert 3-assige versnelling (±8g geconfigureerd) en 3-assige rotatie (±500°/s) via I2C, tot 1000 samples per seconde. Voor skateboard-tricks volstaat 100Hz ruimschoots: een ollie heeft een herkenbare versnellingssignatuur (gewichtloze fase < 6.5 m/s², gevolgd door een landingspiek), en de rotatie van een kickflip of shove-it is duidelijk zichtbaar als een gyroscoop-piek. Een magnetometer (zoals in de duurdere MPU9250) werd bewust niet gekozen: absolute oriëntatie is voor trickdetectie niet nodig, en metalen obstakels in skateparken zouden de magnetometer verstoren.

**Connectiviteit.** Voor draagbaar, batterijgevoed gebruik is Bluetooth Low Energy (BLE) de relevante standaard: laag energieverbruik, voldoende bandbreedte voor een 100Hz datastroom, en ingebouwd in de gekozen ESP32. De vereiste bandbreedte (~15 KB/s aan JSON-telemetrie) valt ruim binnen de BLE-capaciteit.

---

## 2. Bewegingsherkenning: regelgebaseerd vs. machine learning

Er bestaan twee hoofdbenaderingen om uit sensordata een trick te herkennen.

**Machine learning (ML).** Modellen getraind op gelabelde sensordata kunnen bewegingen met hoge nauwkeurigheid classificeren. De opkomst van **TinyML** en **TensorFlow Lite (Micro)** maakt het zelfs mogelijk om dergelijke modellen lokaal op een microcontroller te laten draaien, zonder internetverbinding — relevant voor outdoor skate-sessies (Warden & Situnayake, *TinyML*, O'Reilly, 2019). Het nadeel: ML vereist een grote, gelabelde dataset van tricks. Voor een project van enkele weken, met één skater en één board, is het verzamelen en correct labelen van zo'n dataset onhaalbaar.

**Regelgebaseerd (threshold-based).** Een eenvoudiger en in deze context betrouwbaarder alternatief is detectie op basis van drempelwaarden. Omdat elke trick een fysiek onderscheidende signatuur heeft, kan een toestandsmachine (state machine) de fasen van een trick herkennen:

- **Airtime:** totale versnelling daalt onder ~6.5 m/s² (gewichtloosheid)
- **Rotatie-as bepaalt de trick:** een piek op de gyroscoop X-as (lengteas van het board) = flip (kickflip/heelflip), een piek op de Y-as (verticale as) = shove-it
- **Landing:** een versnellingspiek boven ~15 m/s²

**Keuze voor SK8Sense.** Het prototype gebruikt de **regelgebaseerde aanpak** op de ESP32 zelf. Dit geeft lage latency, vereist geen dataset, en is verklaarbaar (elke detectie is herleidbaar tot een fysieke drempel). De drempelwaarden werden empirisch afgesteld tijdens het testen. ML/TinyML blijft een logische volgende stap voor een toekomstige iteratie, zodra voldoende gelabelde data verzameld is.

---

## 3. Motorisch leren en feedback

Voor het ontwerp van de coaching-feedback is de vraag niet alleen *of* we feedback geven, maar *welke soort* feedback het leren versnelt.

**Externe focus.** Het werk van Gabriele Wulf over de *focus of attention* toont over meer dan vijftien jaar onderzoek consistent aan dat een **externe focus** (aandacht op het effect van de beweging of op het object) leidt tot snellere en duurzamere motorische vaardigheidsverwerving dan een **interne focus** (aandacht op de eigen lichaamsdelen) (Wulf, *Attentional focus and motor learning: a review of 15 years*, International Review of Sport and Exercise Psychology, 2013).

Concreet: een instructie als *"breng je gewicht boven de bolts"* (extern, gericht op het board) werkt beter dan *"buig je knieën"* (intern, gericht op het lichaam).

**Timing van feedback.** Onderzoek naar motorisch leren benadrukt verder dat onmiddellijke, beknopte feedback effectiever is dan uitgestelde of overladen feedback. Skateboard-tricks gebeuren in milliseconden — een menselijke coach kan onmogelijk consistent de exacte fout op timing aanwijzen.

**Relevantie voor SK8Sense.** De AI-coach (Claude Haiku) is expliciet geïnstrueerd om **één korte tip per poging** te geven, in **externe-focus-taal** en in directe skate-cultuurtaal. De tip wordt gegenereerd op basis van de werkelijke sensordata van die poging (piekrotatie, airtime, tail-druk, landingsimpact). Zo vertaalt het systeem ruwe meetdata naar precies het soort feedback dat de literatuur als meest effectief aanwijst.

---

## 4. Gamification en motivatie

Leren skaten vereist veel herhaling, en herhaling vraagt volgehouden motivatie. Hier biedt gamification een onderbouwde oplossing.

**Zelfdeterminatietheorie (SDT).** De motivatietheorie van Deci en Ryan stelt dat intrinsieke motivatie gevoed wordt door drie psychologische basisbehoeften: **competentie** (het gevoel beter te worden), **autonomie** (zelf keuzes maken) en **verbondenheid** (sociale connectie). Goed ontworpen gamification spreekt deze behoeften aan.

**Effectiviteit van gamification.** De literatuurreview van Hamari, Koivisto en Sarsa (*Does Gamification Work? — A Literature Review of Empirical Studies on Gamification*, HICSS, 2014) concludeert dat gamification-elementen zoals punten, badges, levels en voortgangsindicatoren in de meerderheid van de bestudeerde gevallen positieve effecten hebben op betrokkenheid en gedrag — met de kanttekening dat de context en de kwaliteit van de implementatie bepalend zijn.

**Datavisualisatie als motivator.** Apps zoals Strava tonen aan dat ruwe data pas motiveert wanneer ze vertaald wordt naar betekenisvolle inzichten ("je sprong was 15% stabieler dan gisteren") in plaats van losse cijfers. Dit sluit aan bij het principe van *progressieve onthulling* in UX-design (Nielsen Norman Group): toon informatie pas wanneer ze relevant is, om de gebruiker niet te overweldigen.

**Relevantie voor SK8Sense.** Het systeem vertaalt sensordata naar herkenbare voortgang (gedetecteerde tricks, sessiestatistieken, een "readiness index"), spreekt het competentiegevoel aan via zichtbare progressie, en gebruikt een coach-achtige, motiverende tone-of-voice — bewust afgestemd op de skatecultuur (direct, eerlijk, geen corporate taal).

---

## 5. Conclusie

De literatuur onderbouwt de vier pijlers van SK8Sense:

- **IMU-sensoren** zijn betrouwbaar genoeg om skateboard-beweging te meten; een 6-assige sensor volstaat, BLE is de juiste connectiviteit.
- **Trickdetectie** kan regelgebaseerd op basis van fysieke drempelwaarden — een haalbaar en verklaarbaar alternatief voor ML wanneer een trainingsdataset ontbreekt.
- **Feedback** werkt het best wanneer ze onmiddellijk, beknopt en extern gefocust is — precies wat de AI-coach levert.
- **Gamification** is een bewezen middel om motivatie en herhaling te ondersteunen, mits doordacht geïmplementeerd.

De vernieuwing van SK8Sense ligt niet in één afzonderlijke technologie, maar in de combinatie ervan binnen een context — skateboardonderwijs — die tot nu toe technologisch onontgonnen bleef.

---

## Bronnen

*(te verifiëren en aan te vullen met paginanummers vóór indiening)*

- Wulf, G. (2013). *Attentional focus and motor learning: A review of 15 years.* International Review of Sport and Exercise Psychology, 6(1), 77–104.
- Hamari, J., Koivisto, J., & Sarsa, H. (2014). *Does Gamification Work? — A Literature Review of Empirical Studies on Gamification.* Proceedings of the 47th Hawaii International Conference on System Sciences (HICSS).
- Deci, E. L., & Ryan, R. M. (2000). *Self-Determination Theory and the Facilitation of Intrinsic Motivation, Social Development, and Well-Being.* American Psychologist, 55(1), 68–78.
- Warden, P., & Situnayake, D. (2019). *TinyML: Machine Learning with TensorFlow Lite on Arduino and Ultra-Low-Power Microcontrollers.* O'Reilly Media.
- Nielsen Norman Group. *Progressive Disclosure* en *UX guidelines for tracking applications.* nngroup.com
- Espressif Systems. *ESP32 Technical Reference Manual.*
- InvenSense. *MPU-6050 Product Specification (Datasheet).*

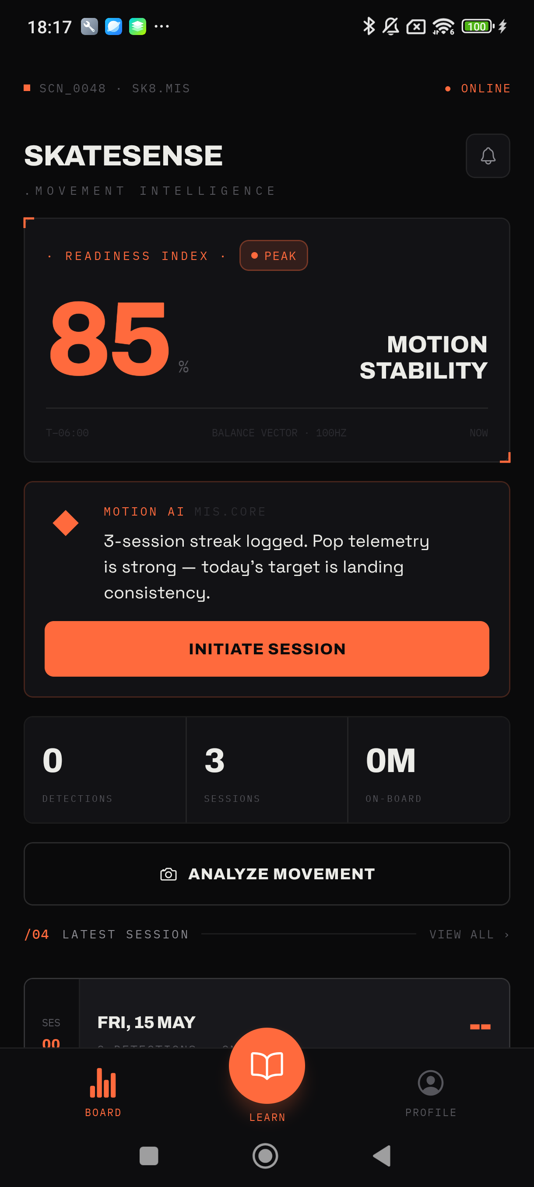
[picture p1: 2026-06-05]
docs/magazine/screenshots/05_profile.png

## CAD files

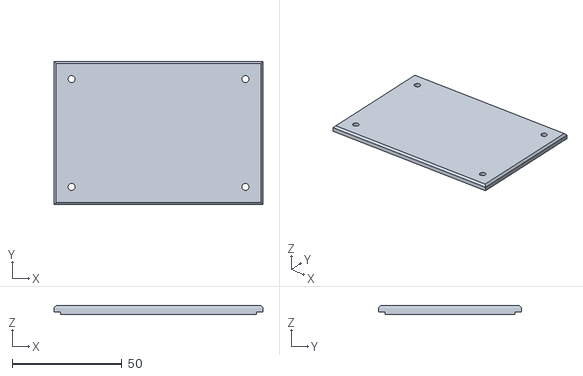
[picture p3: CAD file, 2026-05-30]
hardware/enclosure/electronics_lid.stl
95.0 x 65.0 x 4.00

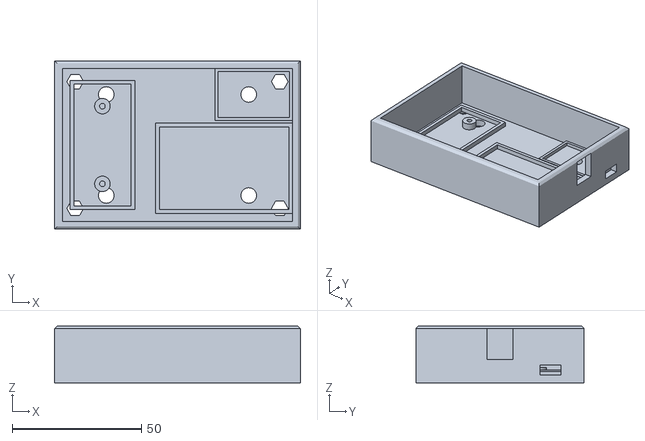
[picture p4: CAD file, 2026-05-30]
hardware/enclosure/electronics_base.stl
95.0 x 65.0 x 22.0

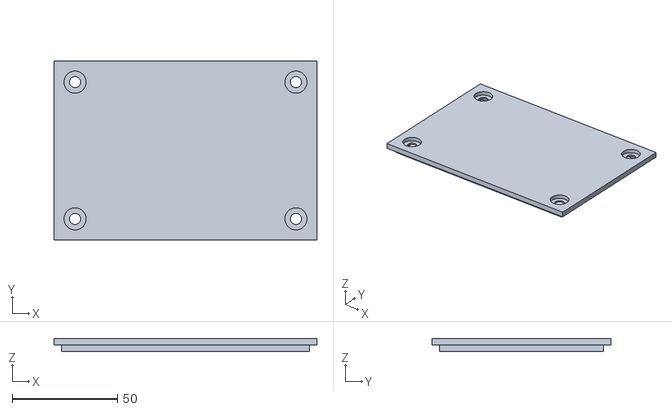
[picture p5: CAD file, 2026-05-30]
hardware/enclosure/skatesense_lid.stl
125.0 x 85.0 x 6.00

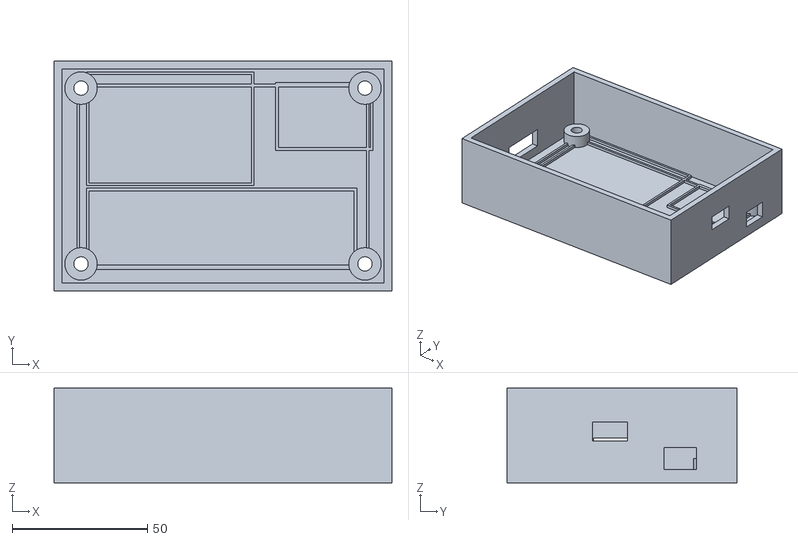
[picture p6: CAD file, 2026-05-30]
hardware/enclosure/skatesense_base.stl
125.0 x 85.0 x 35.0

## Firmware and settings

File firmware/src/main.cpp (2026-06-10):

#include <Arduino.h>
#include <Wire.h>
#include <MPU6050.h>
#include <NimBLEDevice.h>
#include <ArduinoJson.h>
#include <math.h>

#define SERVICE_UUID        "4fafc201-1fb5-459e-8fcc-c5c9c331914b"
#define CHARACTERISTIC_UUID "beb5483e-36e1-4688-b7f5-ea07361b26a8"

#define SDA_PIN 21
#define SCL_PIN 22

// FSR pins
#define FSR_NOSE  34
#define FSR_HEEL  35
#define FSR_TOE   32
#define FSR_TAIL  33

static NimBLECharacteristic* pCharacteristic = nullptr;
MPU6050 mpu;

float ax = 0.0f, ay = 0.0f, az = 9.8f;
float gx = 0.0f, gy = 0.0f, gz = 0.0f;
String trick = "none";

// Board-axis mapping for this physical mount:
//   gx = rawGy: board length axis, kickflip/heelflip rotation
//   gy = rawGx: rail-to-rail board pitch, main ollie movement
//   gz = rawGz: vertical yaw, pop-shuvit movement
//
// A measured kickflip peaks around gx=500 dps with gy much lower. Ollies can
// move both axes, so a flip only wins when gx clearly dominates gy.
#define FLIP_GX_MIN       220.0f
#define FLIP_DOMINANCE    1.35f
#define OLLIE_GY_MIN      150.0f
#define SHUV_GZ_MIN       170.0f
#define SHUV_DOMINANCE    1.25f
#define GYRO_MIN          70.0f
#define TRICK_HOLD_MS     400
#define PEAK_WINDOW_MS    480
#define PEAK_QUIET_MS     80

static unsigned long trickHoldUntil = 0;
static String detectedTrick = "none";
static float peakGx = 0.0f, peakGy = 0.0f, peakGz = 0.0f;
static unsigned long peakWindowStart = 0;
static unsigned long peakLastActive = 0;

void resetPeakWindow() {
    peakWindowStart = 0;
    peakLastActive = 0;
    peakGx = 0.0f;
    peakGy = 0.0f;
    peakGz = 0.0f;
}

String classifyPeakWindow() {
    const float flipPeak = fabsf(peakGx);
    const float olliePeak = fabsf(peakGy);
    const float shuvPeak = fabsf(peakGz);

    if (
        shuvPeak >= SHUV_GZ_MIN &&
        flipPeak < FLIP_GX_MIN &&
        shuvPeak >= olliePeak * SHUV_DOMINANCE
    ) {
        return (peakGz > 0) ? "bs_shuv" : "fs_shuv";
    }

    if (flipPeak >= FLIP_GX_MIN && flipPeak >= olliePeak * FLIP_DOMINANCE) {
        return (peakGx > 0) ? "kickflip" : "heelflip";
    }

    if (olliePeak >= OLLIE_GY_MIN) {
        return "ollie";
    }

    return "none";
}

void detectTrick(float gx_dps, float gy_dps, float gz_dps) {
    const unsigned long now = millis();
    const float gyroMag = sqrtf(
        gx_dps * gx_dps +
        gy_dps * gy_dps +
        gz_dps * gz_dps
    );

    if (now < trickHoldUntil) {
        trick = detectedTrick;
        return;
    }

    const bool active = gyroMag > GYRO_MIN;
    if (active) {
        if (peakWindowStart == 0) peakWindowStart = now;
        peakLastActive = now;
        if (fabsf(gx_dps) > fabsf(peakGx)) peakGx = gx_dps;
        if (fabsf(gy_dps) > fabsf(peakGy)) peakGy = gy_dps;
        if (fabsf(gz_dps) > fabsf(peakGz)) peakGz = gz_dps;
    }

    if (peakWindowStart == 0) {
        trick = "none";
        return;
    }

    const bool quietEnough = !active && (now - peakLastActive >= PEAK_QUIET_MS);
    const bool windowDone = now - peakWindowStart >= PEAK_WINDOW_MS;
    if (!quietEnough && !windowDone) {
        trick = "none";
        return;
    }

    detectedTrick = classifyPeakWindow();
    resetPeakWindow();

    if (detectedTrick == "none") {
        trick = "none";
        return;
    }

    trickHoldUntil = now + TRICK_HOLD_MS;
    trick = detectedTrick;
}

void setup() {
    Serial.begin(115200);
    Wire.begin(SDA_PIN, SCL_PIN);
    Wire.setClock(100000);

    mpu.initialize();
    if (!mpu.testConnection()) {
        Serial.println("MPU6050 FAILED");
    } else {
        Serial.println("MPU6050 OK");
    }
    mpu.setFullScaleAccelRange(MPU6050_ACCEL_FS_8);
    mpu.setFullScaleGyroRange(MPU6050_GYRO_FS_500);

    // FSR pins are input-only ADC; no pinMode needed.
    Serial.print("FSR pins: nose="); Serial.print(FSR_NOSE);
    Serial.print(" heel="); Serial.print(FSR_HEEL);
    Serial.print(" toe="); Serial.print(FSR_TOE);
    Serial.print(" tail="); Serial.println(FSR_TAIL);

    NimBLEDevice::init("SK8Sense");
    NimBLEServer* pServer = NimBLEDevice::createServer();
    NimBLEService* pService = pServer->createService(SERVICE_UUID);
    pCharacteristic = pService->createCharacteristic(
        CHARACTERISTIC_UUID,
        NIMBLE_PROPERTY::READ | NIMBLE_PROPERTY::NOTIFY
    );
    pService->start();
    NimBLEAdvertising* pAdvertising = NimBLEDevice::getAdvertising();
    pAdvertising->addServiceUUID(SERVICE_UUID);
    pAdvertising->start();
    Serial.println("SK8Sense BLE advertising started");
}

void loop() {
    // Read IMU
    int16_t rawAx, rawAy, rawAz, rawGx, rawGy, rawGz;
    mpu.getMotion6(&rawAx, &rawAy, &rawAz, &rawGx, &rawGy, &rawGz);

    // Sensor is mounted rotated 90 degrees: swap ax/az so az = gravity when flat.
    az = (rawAx / 4096.0f) * 9.81f;
    ay = (rawAy / 4096.0f) * 9.81f;
    ax = -1.0f * (rawAz / 4096.0f) * 9.81f;
    gx = rawGy / 65.5f;
    gy = rawGx / 65.5f;
    gz = rawGz / 65.5f;

    // Read FSRs (12-bit ADC, scale to 0-1023 for compact JSON)
    int f1 = analogRead(FSR_NOSE) >> 2;
    int f2 = analogRead(FSR_HEEL) >> 2;
    int f3 = analogRead(FSR_TOE)  >> 2;
    int f4 = analogRead(FSR_TAIL) >> 2;

    detectTrick(gx, gy, gz);

    // BLE JSON; compact to fit in 185 byte MTU.
    StaticJsonDocument<220> doc;
    doc["ax"] = round(ax * 10) / 10.0;
    doc["ay"] = round(ay * 10) / 10.0;
    doc["az"] = round(az * 10) / 10.0;
    doc["gx"] = round(gx * 10) / 10.0;
    doc["gy"] = round(gy * 10) / 10.0;
    doc["gz"] = round(gz * 10) / 10.0;
    doc["trick"] = trick;
    doc["f1"] = f1;
    doc["f2"] = f2;
    doc["f3"] = f3;
    doc["f4"] = f4;

    char buf[220];
    serializeJson(doc, buf, sizeof(buf));

    pCharacteristic->setValue((uint8_t*)buf, strlen(buf));
    if (NimBLEDevice::getServer()->getConnectedCount() > 0) {
        pCharacteristic->notify();
    }

    // Print sensor data every 500ms
    static unsigned long lastPrint = 0;
    if (millis() - lastPrint >= 500) {
        lastPrint = millis();
        Serial.printf("ax=%.1f ay=%.1f az=%.1f | gx=%.1f gy=%.1f gz=%.1f | f1=%d f2=%d f3=%d f4=%d | trick=%s\n",
            ax, ay, az, gx, gy, gz, f1, f2, f3, f4, trick.c_str());
    }

    delay(10); // 100Hz
}

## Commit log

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2026-05-02 feat(app): complete MVP1 UI - session flow, trick feed, history, 3-trick simulation
2026-05-03 fix(app): BLE data parsing, throttle 10Hz, 3-trick firmware, MTU fix
    [main.cpp]
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2026-05-09 feat(app): Firebase Auth + Firestore + profile screen + progress chart
    - Add Firebase JS SDK + AsyncStorage to dependencies
    - Add app/config/firebase.js (placeholder config, fill in from Firebase Console)
    - Add authStore: email/password login, register, logout, onAuthStateChanged
    - Add LoginScreen + RegisterScreen with validation and error handling
    - Add ProfileScreen: avatar, all-time stats, per-trick bar chart, sign out
    - Update sessionStore: auto-save sessions to Firestore on stopSession
    - Update sessionStore: loadSessions() fetches from Firestore on History open
    - Update App.js: auth-gated navigation (Onboarding → Login/Register → App)
    - Update OnboardingScreen: onComplete prop inste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
2026-05-09 feat(app): bottom tab navigation + Learning screen with trick library
    - Add @react-navigation/bottom-tabs
    - Add app/navigation/MainTabs.js: custom tab bar with elevated middle button
    - Board tab (left): Home → Connect → Dashboard → SessionSummary stack
    - Learn tab (middle, elevated): trick library
    - Profile tab (right): Profile → History stack
    - Add app/data/tricks.js: 23 tricks across 5 difficulty levels with tips
    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
2026-05-10 feat(app): trick store and navigation from list to intro
    - Add trickStore.js: Ollie/Kickflip/Heelflip data with steps + coaching tips
    - Add actions: selectTrick, completeStep, addAttempt, startSession, endSession
    - Update LearningScreen: detectable tricks navigate to TrickIntro, others open modal
    - Add LearnNavigator stack: TrickList → TrickIntro → Practice → PracticeSummary
    - Add placeholder screens for step 2-4
2026-05-10 feat(app): trick intro screen with steps and tips
    - Dark design system (#0a0a0a bg, #d4ff3d accent)
    - Trick name with colored left border accent
    - Difficulty + category tags
    - 5 expandable step cards with external-focus tips
    - SK8Sense detectable badge
    - START PRACTICE CTA button (electric lime)
2026-05-10 feat(app): practice screen with step-by-step learning flow
    - Step phase: 5 steps per trick with tip card, progress dots
    - I TRIED IT button triggers 1.5s detect animation
    - 75% success rate per step (simulated), 60% in combine phase
    - Success: step advances with color feedback
    - After all steps: enters COMBINE phase (full attempt)
    - After 5 combine attempts: mini-pause modal
    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
2026-05-10 feat(app): practice summary screen with XP and progress
    - Duration, total attempts, landed count
    - Success rate with colored progress bar
    - XP: 10 per landed, +50 bonus for 100%
    - Unlock message if >= 70%: shows next trick name
    - Next session tip (external focus, per trick)
    - BACK TO TRICKS button
2026-05-10 feat(app): animated 3D skateboard visualizer on practice screen
    - SkateboardView component: deck, trucks, wheels, grip tape
    - 4 animated FSR pressure zones (tail, nose, heel, toe) glow in trick color
    - Front/back foot silhouettes on deck
    - Step-specific animations:
    - Step 1: foot position glow + idle wobble
    - Step 2: tail pop flash + board tilt
    - Step 3: board lifts + heel zone lights up
    - Step 4: board high in air + nose glow
    - Step 5: landing impact flash (all zones)
    - Combine: full trick loop (pop → fly → spin → land)
    - 3D perspective transform (rotateX/Y/Z + translateY)
    - Shadow shrinks as board lifts for depth illusion
    - Board shakes on detect animation
    Co-Authored-By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
2026-05-10 feat(app): real 3D skateboard with Three.js (expo-gl + expo-three)
    - Full 3D geometry: deck, grip tape, concave strips, trucks (baseplate
    + hanger + kingpin), axles, wheels with hubs and bearings, bolts
    - PBR-style lighting: ambient + key + fill + accent point light
    - Ground plane + dynamic shadow (shrinks/fades as board lifts)
    - Scene fog for depth
    - 4 emissive pressure zones (tail/nose/heel/toe) glow in trick color
    - Step 1: foot position zones pulse, idle wobble
    - Step 2: pop animation with tail flash and board lift
    - Step 3: heel zone + board rise and tilt
    - Step 4: nose glow + board level in air with rotation
    - Step 5: landing impact all zones fla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
2026-05-10 fix(app): remove expo-gl/expo-three (incompatible with RN 0.81.5)
    Replace Three.js WebGL renderer with high-quality Animated skateboard:
    - Deck with grip tape, concave strips, trucks, wheels, bolts, foot silhouettes
    - 4 pressure zones glow in trick color per step
    - Full 3D perspective transforms (rotateX/Y/Z + translateY)
    - Step-specific animations: foot position, pop, slide, level out, landing
    - Combine phase: full trick loop (load → pop → spin → land → impact flash)
    - Dynamic shadow shrinks/fades as board lifts
    - No native dependencies required
2026-05-10 feat(app): real 3D skateboard GLB via WebView + Three.js
    - Add skateboard.glb (Sketchfab model) to assets
    - Install react-native-webview, expo-asset, expo-file-system
    - SkateboardGL: WebView loads GLB via expo-asset → base64 → GLTFLoader
    - Three.js r134 from CDN renders the real 3D model
    - ACES filmic tone mapping + directional/point lights
    - Accent PointLight pulses in trick color
    - Step-based animations: idle wobble, pop, slide, level out, landing, combine loop
    - Dynamic shadow + scene fog
    - Loading spinner while model parses
2026-05-10 feat(app): procedural 3D skateboard — no GLB, full Three.js geometry
    - Deck with nose/tail kicks (~12°/17° angles), veneer strips, grip tape
    - Concave edge strips along both sides
    - 4 pressure zones (tail/nose/heel/toe) glow in trick color
    - Full truck assembly: baseplate, hanger, kingpin, axle, nuts
    - Wheels with hubs + bearings + axle nuts
    - PCF soft shadows on ground plane
    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
2026-05-10 feat(app): skate shoes + leg animations + correct FSR sensor zones
    - Add realistic skate shoe geometry per foot:
    thick cupsole, upper, toe box, heel counter, tongue, ankle collar, sock, lower leg/knee
    - Back foot (regular stance): perpendicular on tail, z=1.65
    - Front foot: 47° angle on front trucks, z=-1.25
    - Step-specific foot animations:
    - Step 1 Foot Position: both feet in skating stance, gentle idle
    - Step 2 Pop: back foot loads + snaps tail, ankle bends, feet lift
    - Step 3 Slide: front foot slides toward nose (z=-1.25→-1.8), ankle action
    - Step 4 Level Out: front foot pushes nose down, back foot elevated
    - Step 5 Landing: both feet stomp impact with bounce
    - Combine: f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
2026-05-10 feat(app): replace 3D WebView with clean 2D top-down skateboard
    - Pure React Native Animated, no WebView, no CDN, instant load
    - Top-down board view: deck, grip tape, trucks, wheels, bolts, concave lines
    - 4 FSR zones at correct positions (tail/nose/heel/toe) glow in trick color
    - Back foot: perpendicular at tail area with toe detail
    - Front foot: 42deg angled over front trucks with toe tip
    - Step animations:
    - Foot Position: idle wobble + tail/heel gentle pulse
    - Pop: back foot presses tail → board lifts → lands with impact flash
    - Slide: front foot slides toward nose + heel/toe zones glow
    - Level Out: board stays elevated + front foot on nose + nose glow
    - Landing: stomp with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
2026-05-10 feat(app): live 3D board viewer with IMU rotation + trick state machine
    LiveBoardViewer component:
    - WebView + Three.js r134 + GLTFLoader
    - Loads skateboard.glb from assets via expo-asset/FileSystem
    - Auto-centers + auto-scales model, fits camera to bounds
    - Receives {type:'sensor', pitch, roll, yaw} via postMessage
    - Smooth lerp: pitch*0.15, roll*0.15, yaw*0.10
    - board.rotation.x = pitchRad, .z = -rollRad, .y = yawRad
    - Simulated ollie demo when no real sensor / web mode
    - Trick glow: PointLight pulse on trick detection
    - Falls back to sim mode if GLB fails to load
    DashboardScreen updates:
    - Import + render LiveBoardViewer (190px, replaces sensor grid)
    - calcPitchRoll(): atan2 from ax/ay/a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
2026-05-15 fix(app): replace WebView GLB with instant pure-RN animated board viewer
    LiveBoardViewer is now pure React Native Animated - no WebView, no GLB,
    no CDN. Responds instantly to pitch/roll via perspective transforms:
    - rotateX = pitch (nose up/down)
    - rotateZ = roll (left/right tilt)
    - Smooth 80ms lerp on each sensor update
    - Trick glow: blue flash on nose/tail zones on trick detection
    - Simulated idle rotation when no real sensor connected
    - Live pitch/roll values overlaid on deck
2026-05-15 fix(app): live pitch/roll by computing from sensorData in render
    Root cause: stale closure in BLE callback prevented separate pitch/roll
    state from updating. Fix: compute livePitch/liveRoll/liveImpact directly
    from sensorData in the render function — sensorData is always fresh from
    bleStore, so no closure issues. calibRef uses useRef so calibration works
    without re-creating the BLE subscription.
2026-05-15 feat(app): 3D GLB board via URI fetch + calibration feedback + UI improvements
    LiveBoardViewer:
    - Load 4.2MB GLB via fetch(localUri) instead of base64 postMessage
    → much faster, no 5.6MB string transfer
    - Uses allowFileAccess + allowUniversalAccessFromFileURLs on WebView
    - Two-step load: RN gets asset URI → sends 'go' → WebView fetches
    - OrbitControls: user can drag/zoom the 3D model
    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
2026-05-15 fix(app): revert to base64 GLB loading, fix camera angle for flat board
    - Back to reliable base64 via expo-file-system (Metro URL caused CORS errors)
    - Camera at 3/4 side-front-above angle instead of top-down
    - Camera refit uses r*1.2/r*1.0/r*2.8 offsets for natural view
    - OrbitControls: user can drag to adjust view
    - Debug overlay shows raw x/y/z dims for 4s after load
    - Auto-orient: Y-tallest → lay flat, X-longest → rotate Y 90deg
2026-05-15 fix(app): camera angle - higher + farther to show full board
2026-05-15 fix(app): camera perpendicular to long axis (x=0.76 model)
2026-05-15 fix(app): drop broken 3D WebView, use polished 2D board with perspective
    The GLB WebView approach had persistent OrbitControls conflicts.
    The 2D board works reliably and looks good with perspective transforms.
    - Dark deck with grip tape, trucks, wheels, bolts, concave strips
    - Back + front foot silhouettes in skating stance
    - 4 FSR zones glow blue on trick detection + bounce animation
    - 80ms lerp for smooth live pitch/roll from ESP32 MPU6050
    - Simulated idle rotation when not connected
    - Live angle display on deck (pitch°/roll°)
    - Shadow opacity follows board tilt
2026-05-15 feat(app): polish HomeScreen, ConnectScreen, ProfileScreen
    HomeScreen:
    - Personal greeting (Hey, Kylian)
    - Pulsing rings on scan button with glow
    - Last session preview card
    - Circular scan CTA button
    ConnectScreen:
    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
2026-05-15 feat(app): use Google model-viewer for 3D GLB rendering
    model-viewer handles auto-centering, scaling and camera orientation
    automatically. Applies sensor pitch/roll to mv.model.rotation.
    Falls back to polished 2D board if GLB fails to load.
    Keeps camera-controls so user can orbit the model.
2026-05-16 feat(fsr): integrate FSR sensors — firmware + app
    Firmware (main.cpp):
    - Add FSR pin definitions: nose=34, heel=35, toe=32, tail=33
    - analogSetAttenuation(ADC_11db) for 0-3.3V range
    - Read f1/f2/f3/f4 (0-4095) every loop iteration
    - Improved trick detection: FSR tail spike confirms pop
    - Pop: f4 > 1800 OR mag < 7 (airtime)
    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
2026-05-16 feat(esp32): FSR sensor integration on GPIO 34 (nose)
    - Read 4 FSR sensors: nose(34), heel(35), toe(32), tail(33)
    - 12-bit ADC → scaled to 0-1023 range
    - f1/f2/f3/f4 fields added to BLE JSON payload
    - Serial debug only prints when FSR > 100 (silent otherwise)
    - Tested: nose FSR reads 0→3600+ under pressure ✓
2026-05-16 feat(app): FSR pressure bars + enhanced trick detection
    - Parse f1/f2/f3/f4 from BLE data (300 ADC noise floor threshold)
    - Add 4 FSR pressure bars: NOSE/HEEL/TOE/TAIL with color per zone
    - bleStore initial state includes f1-f4
    - Trick state machine uses FSR tail pressure for pop detection:
    tailPressure > 800 → 'pop' state (more reliable than accel only)
2026-05-16 feat(app): procedural 3D skateboard with live FSR zone glow
    LiveBoardViewer rebuilt with Three.js (no GLB/model-viewer):
    - Procedural deck with nose/tail kicks (ExtrudeGeometry-style)
    - Grip tape, concave strips, veneer edges, bolt markers
    - Full truck assemblies: baseplate, hanger, kingpin, axle
    - Wheels with hub + bearing
    - 4 FSR pressure zones on correct positions:
    TAIL (red #e94560) / NOSE (green) / HEEL (blue) / TOE (orange)
    - emissiveIntensity maps to real FSR sensor value in real-time
    - Dynamic PointLight pulses in the color of the active zone
    - Fixed 3/4 camera (no OrbitControls = no conflicts)
    - Board rotates with pitch/roll from MPU6050
    - Simulated demo mode when not connected
    D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
2026-05-16 feat(app): rewrite 3D board with realistic materials + refined FSR zones
    - ExtrudeGeometry deck with proper rounded nose/tail outline (Shape)
    - Nose kick (20°) + tail kick (27°) with grip tape overlays
    - Concave effect: two slightly-angled edge strips on grip tape
    - Maple bottom face (warm wood color), matte dark grip tape
    - Cleaner trucks: thin baseplate, T-hanger, metallic axle, hex nuts
    - Urethane wheels: cream/off-white, TorusGeometry edge rings, hub, bearing
    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
2026-05-16 fix(app): trick state machine driven by ESP32 output + FSR tail
    - Use data.trick from ESP32 firmware as primary state source
    - tail FSR > 600 → 'pop' state (was 800+300=1100 before, too high)
    - trick !== 'none' → 'airtime' (ESP32 is in airtime/landing phase)
    - After airtime clears → 'ollie' for 1.5s then back to waiting
    - Simpler and more reliable than threshold-based IMU detection
2026-05-16 revert(app): restore fast 3D board (before design rewrite)
2026-05-16 perf(app): design board without shadows — 3x faster
    Restored design version (d3af2a7) with performance fixes:
    - shadowMap.enabled=false (biggest gain)
    - pixelRatio max 1.5
    - bevelSegments 6→3
    - Wheel segments 28→16, removed TorusGeometry rings
    - ShadowMaterial→MeshPhongMaterial ground
    - Removed all castShadow/receiveShadow calls
2026-05-16 fix(app): replace WebView Three.js with pure RN Animated — zero lag
    WebView postMessage latency made the board fall behind live sensor data.
    Pure React Native Animated has zero bridge overhead:
    - 60ms timing for pitch/roll (instant feel)
    - 50ms for FSR zones
    - perspective + rotateX/Z transforms for 3D tilt
    - FSR zones glow directly from sensor values
2026-05-16 fix(app): 3D board back + lerp 0.16→0.45 for instant response
    lerp 0.45 at 60fps = 90% target in ~75ms (same as Animated 60ms)
2026-05-20 fix(app): 3D board at 100Hz via forwardRef/useImperativeHandle
    - LiveBoardViewer: forwardRef + useImperativeHandle exposes update()
    - DashboardScreen: boardRef.current.update() called in BLE callback at full
    sensor rate (100Hz), bypassing the 10Hz React state throttle
    - 3D board rotation now follows sensor data with <16ms latency instead of 100ms
2026-05-22 fix(esp32): slow I2C clock for perfboard reliability
    [main.cpp]
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2026-05-28 fix(app): filter BLE scan by service UUID to show only SK8Sense
2026-05-28 fix(app): scan all devices, filter by name SK8Sense
2026-05-28 fix(app): keep original BLE device object so connect() works
2026-05-28 fix(esp32+app): include name in BLE advertisement + show all scan results
    [main.cpp]
2026-05-28 fix(app+esp32): active BLE scan + UUID filter with name fallback
    [main.cpp]
2026-05-28 fix(app): remove invalid scanMode, scan all devices
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2026-05-30 fix(app): INITIATE SESSION button works + Learn screen v3 redesign
    - V3Shared: TouchableOpacity for CTA button (was non-clickable Text)
    - LearningScreen: v3 neo-brutalist design, only Ollie/Kickflip/Pop Shuv-it
    - Ticked panels, mono labels, coming soon grid with locked cards
    - Motion AI roadmap banner at bottom
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2026-05-30 chore: add design files, 3D models and enclosure files
    [electronics_base.stl, electronics_lid.stl, skatesense_base.stl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]
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2026-06-03 feat(app): TrickIntro + Practice screens in MIS v3 design
    - TrickIntro: grid overlay, ticked title panel, mono labels, section heads
    - Practice: v3 step bar, instruction card, sensor badge, round modal with corner ticks
    - Orange accent replaces lime, Archivo/mono/body fonts throughout
    - Kept all detection and animation logic intact
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2026-06-05 chore: clean final project structure
    [electronics_base.stl, electronics_lid.stl, skatesense_base.stl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]
2026-06-10 Improve session stability and coaching UI
    [main.cpp]
